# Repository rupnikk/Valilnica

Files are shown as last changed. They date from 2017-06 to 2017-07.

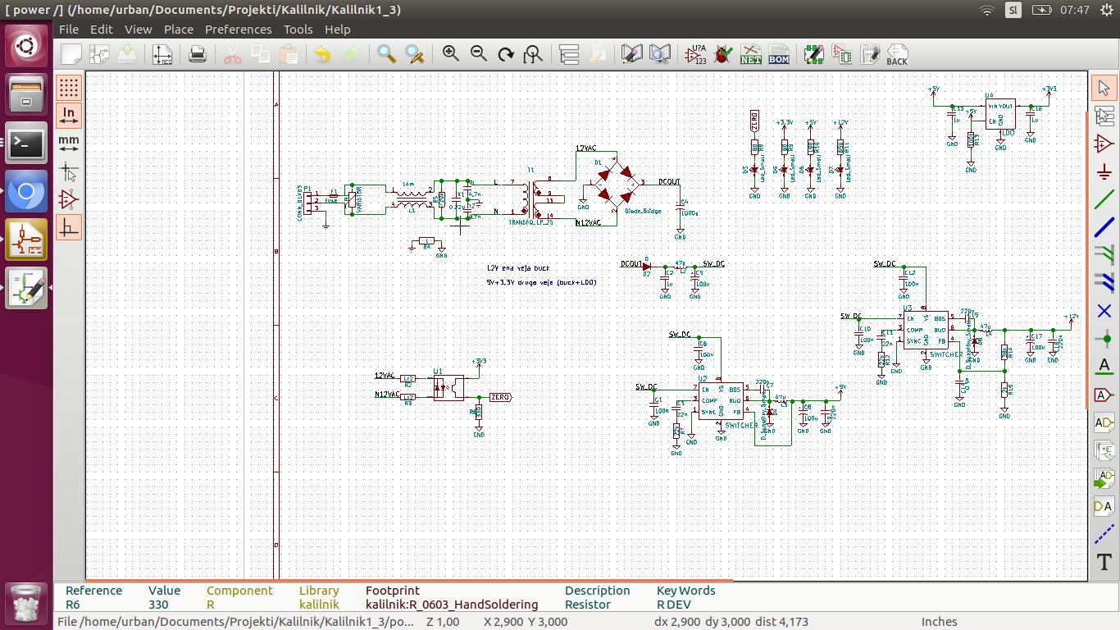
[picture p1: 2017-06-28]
napajanje.jpg

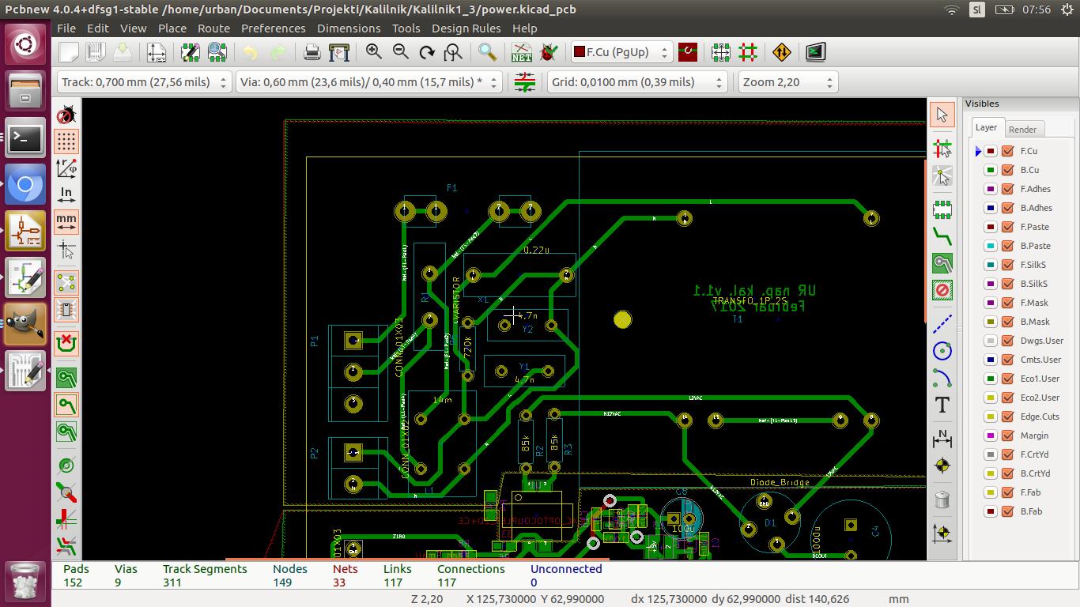
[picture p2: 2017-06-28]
napajanje_pcb.jpg

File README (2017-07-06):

KALILNIK

Urban Rupnik
Zadlog 42, 5274 Črni Vrh
Start: 6. 6. 2016

Navodila za git:
git add . -Af
git commit -am "bla"

Verzija 1.1: 6. 6. 2016
Komentarji k shemi:
	LCD: 	- potenciometer za nastavljanje svetlosti, 
			- R/W = GND => se samo piše v spomin LCD-ja

	Izhodi:	- Luci:		-180 omski upor za nastavitev napetosti, ki 					mora biti na triacu in zagotovitev odprtja 						triaca.
						- 2.4 ohm + 0.2uF -> Snubber za optospojnik
						- 39 ohm + 0.05uF -> Snubber za induktivno breme
			- Grelec:	- brez Snubberjev zato ker je omsko breme

	Tipke: 	- paralelni upor -> pull-up upor (cca. 10k)
			- serijski upor -> ko je pin nastavljen kot vhod in je tipka pritisnjena (nizko stanje na vhodu) skozi tranzistor steče tok, ki je zaradi velike Ugs prevelik in lahko uniči pin. (cca. 220 ohm)

	Enkoder: - 10k pull-up upor, in 10k + 0.1uF C za filter

	MCU: 	- Potrebujemo najmanj 21 digitalnih I/O pinov => najmanjši tak je 32 pinski.
			- ne potrebujemo veliko spomina, niti procesorske moči, tako da bi se odločil za ATtiny88 NIMA možnosti za zunanji kristalni oscilator!!!!!!!!
		- Izbral sem ATMEGA32M1-AU

	Switcher: -http://si.farnell.com/infineon/ifx91041ej-v50/dc-dc-conv-buck-370khz-soic-8/dp/2432504

			- blokirni kondenzatorji cca. 2.2u in 100n

			- pi filter: (1/10*f0) f0=1/(2*pi*sqrt(L*C))

	konektorji: signalni: -jst xhp
			močnostni: 5.08 mm bom potem zbral

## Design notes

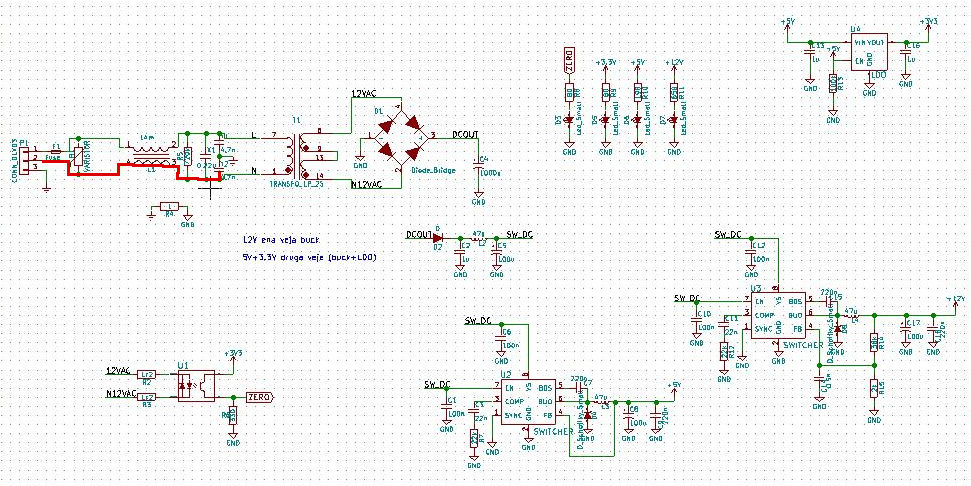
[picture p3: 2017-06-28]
napajanje.png

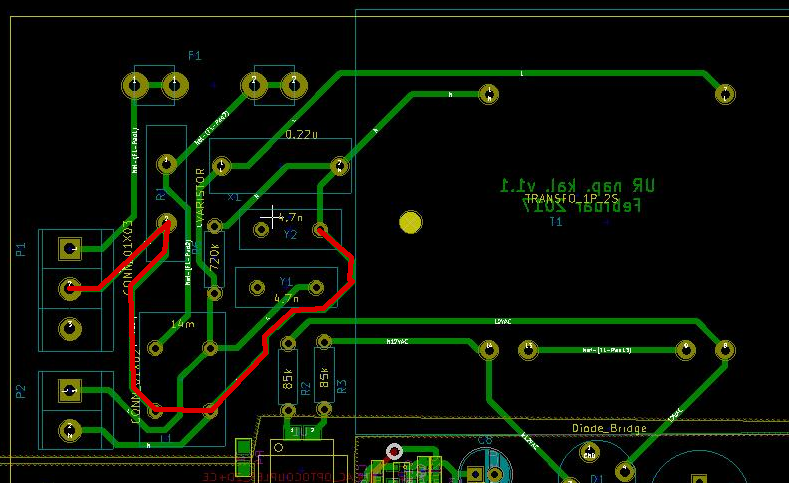
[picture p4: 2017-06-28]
napajanje_pcb.png

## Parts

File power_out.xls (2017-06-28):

Reference | Value | Footprint | Datasheet | Farnell number | Farnell numbere
P4 | CONN_02X03 | kalilnik:IDC_Header_Straight_6pins
U1 | TRIAC_OPTOCOUPLER | kalilnik:DIP-6_W7.62mm_LongPads | http://www.farnell.com/datasheets/2050807.pdf | 1045437
D3 | Led_Small | kalilnik:LED_0_1inch
R4 | 220 | kalilnik:R_0603_HandSoldering
R6 | 180 | kalilnik:CFR100
R8 | 2k4 | kalilnik:CFR100
C3 | 200n | kalilnik:C_5x11_2 | http://www.farnell.com/datasheets/1558295.pdf?_ga=1.154452152.1660152525.1481320514 |  | 1902939
U3 | TRIAC | kalilnik:SOT428_2+1P | http://www.farnell.com/datasheets/1837712.pdf?_ga=1.37489763.278307822.1459272424 | 1757883
R10 | 39 2W | kalilnik:CFR200
C5 | 50n 500V+ | kalilnik:c_60pF |  | 2546307
P5 | CONN_01X02 | kalilnik:CONN_2x1x5.08
D4 | Led_Small | kalilnik:LED_0_1inch
R5 | 220 | kalilnik:R_0603_HandSoldering
R1 | R | kalilnik:R_0603_HandSoldering
D2 | Led_Small | kalilnik:R_0603_HandSoldering
R2 | 220 | kalilnik:R_0603_HandSoldering
R3 | 10k | kalilnik:R_0603_HandSoldering
SW1 | SW_PUSH | kalilnik:TACTILE_SWTICH_4PIN | http://www.farnell.com/datasheets/1914518.pdf?_ga=1.146154420.1660152525.1481320514 | 2320087
C1 | 1u | kalilnik:C_0603_HandSoldering
C2 | 100n | kalilnik:C_0603_HandSoldering
D1 | ESD_1CH | kalilnik:SOD323F | http://www.farnell.com/datasheets/682594.pdf?_ga=1.121054984.1660152525.1481320514 | 8737517
IC1 | ATTINY85-S | kalilnik:SOIC-8_3.9x4.9mm_Pitch1.27mm | http://www.farnell.com/datasheets/1744708.pdf?_ga=1.222685467.1660152525.1481320514 | 1972176
P1 | CONN_01X02 | kalilnik:CONN_2x1x2.54
P2 | CONN_01X02 | kalilnik:CONN_2x1x5.08
U2 | TRIAC_OPTOCOUPLER | kalilnik:DIP-6_W7.62mm_LongPads | http://www.farnell.com/datasheets/2050807.pdf | 1045437
R7 | 180 | kalilnik:CFR100
R9 | 2k4 | kalilnik:CFR100
C4 | 200n | kalilnik:C_5x11_2 | http://www.farnell.com/datasheets/1558295.pdf?_ga=1.154452152.1660152525.1481320514 |  | 1902939
U4 | TRIAC | kalilnik:SOT428_2+1P | http://www.farnell.com/datasheets/1837712.pdf?_ga=1.37489763.278307822.1459272424 | 1757883
R11 | 39 2W | kalilnik:CFR200
C6 | 50n 500V+ | kalilnik:c_60pF |  | 2546307
P6 | CONN_01X02 | kalilnik:CONN_2x1x5.08
P3 | CONN_01X03 | kalilnik:CONN_3x1x2.54

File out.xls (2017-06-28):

Reference | Value | Footprint | Datasheet | Farnell number
P3 | CONN_02X03 | kalilnik:IDC_Header_Straight_6pins
R1 | 80 | kalilnik:R_0603_HandSoldering
D2 | Led_Small | kalilnik:R_0603_HandSoldering
R4 | 220 | kalilnik:R_0603_HandSoldering
R5 | 10k | kalilnik:R_0603_HandSoldering
SW1 | SW_PUSH | kalilnik:TACTILE_SWTICH_4PIN
C1 | 1u | kalilnik:C_0603_HandSoldering
C2 | 100n | kalilnik:C_0603_HandSoldering
D1 | ESD_1CH | kalilnik:SOD323F | http://www.farnell.com/datasheets/682594.pdf?_ga=1.121054984.1660152525.1481320514 | 8737517
P2 | CONN_01X02 | kalilnik:CONN_2x1x2.54
IC1 | ATTINY24A-SS | kalilnik:SOIC-14_3.9x8.7mm_Pitch1.27mm
P1 | CONN_01X04 | kalilnik:CONN_4x1x2.54
R10 | 220 | kalilnik:R_0603_HandSoldering
P9 | CONN_01X05 | kalilnik:CONN_5x1x2.54
Q1 | Q_NMOS_GDS | kalilnik:SOT89-3_Housing_Handsoldering_123 | http://www.farnell.com/datasheets/612773.pdf?_ga=1.108842754.1660152525.1481320514 | 1834055
R12 | 220 | kalilnik:R_0603_HandSoldering
Q3 | Q_NMOS_GDS | kalilnik:SOT89-3_Housing_Handsoldering_123 | http://www.farnell.com/datasheets/612773.pdf?_ga=1.108842754.1660152525.1481320514 | 1834055
R13 | 220 | kalilnik:R_0603_HandSoldering
Q4 | Q_NMOS_GDS | kalilnik:SOT89-3_Housing_Handsoldering_123 | http://www.farnell.com/datasheets/612773.pdf?_ga=1.108842754.1660152525.1481320514 | 1834055
Q5 | Q_NMOS_GDS | kalilnik:SOT89-3_Housing_Handsoldering_123 | http://www.farnell.com/datasheets/612773.pdf?_ga=1.108842754.1660152525.1481320514 | 1834055
R14 | 220 | kalilnik:R_0603_HandSoldering
R2 | 190 | kalilnik:R_0603_HandSoldering
D3 | Led_Small | kalilnik:R_0603_HandSoldering
R3 | 650 | kalilnik:R_0603_HandSoldering
D4 | Led_Small | kalilnik:R_0603_HandSoldering
Q2 | Q_NMOS_GDS | kalilnik:SOT89-3_Housing_Handsoldering_123 | http://www.farnell.com/datasheets/612773.pdf?_ga=1.108842754.1660152525.1481320514 | 1834055
R11 | 220 | kalilnik:R_0603_HandSoldering
P8 | CONN_01X02 | kalilnik:CONN_2x1x5.08
P5 | CONN_01X03 | kalilnik:CONN_3x1x2.54
P4 | CONN_01X03 | kalilnik:CONN_3x1x2.54
P7 | CONN_01X03 | kalilnik:CONN_3x1x2.54
P6 | CONN_01X03 | kalilnik:CONN_3x1x2.54
R8 | 4.7k | kalilnik:R_0603_HandSoldering
R6 | 4.7k | kalilnik:R_0603_HandSoldering
R7 | 4.7k | kalilnik:R_0603_HandSoldering
R9 | 4.7k | kalilnik:R_0603_HandSoldering

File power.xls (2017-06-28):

Reference | Value | Footprint | Datasheet | Farnell number
U4 | LDO | kalilnik:SOT23-5 | http://www.farnell.com/datasheets/1720528.pdf?_ga=1.150340662.1660152525.1481320514 | 2363036
C13 | 1u | kalilnik:C_0603_HandSoldering
R13 | 100k | kalilnik:R_0603_HandSoldering
C16 | 1u | kalilnik:C_0603_HandSoldering
F1 | Fuse | kalilnik:Fuseholder_Fuse_5x20 | http://www.farnell.com/datasheets/2036023.pdf?_ga=1.179105700.1660152525.1481320514 | 1271632
R1 | VARISTOR | kalilnik:VARISTOR_MOV-14D431KTR | http://www.farnell.com/datasheets/2026684.pdf?_ga=1.122545291.1660152525.1481320514 | 2250941
C4 | 1000u | kalilnik:C_13_21_5 | http://www.farnell.com/datasheets/1723232.pdf?_ga=1.246941828.1660152525.1481320514 | 9451323
D1 | Diode_Bridge | kalilnik:CIRC_BRIDGE_RECT
C2 | 1u | kalilnik:R_0603_HandSoldering
L2 | 47u | kalilnik:TYS4018470M-10 | http://www.farnell.com/datasheets/1685911.pdf?_ga=1.73640273.278307822.1459272424 | 2292522
C6 | 100n | kalilnik:C_0603_HandSoldering
U2 | SWITCHER | kalilnik:SOIC-8-N | http://www.farnell.com/datasheets/1836350.pdf?_ga=1.108659649.278307822.1459272424 | 2432504
C5 | 100u | kalilnik:C_Radial_D6.3_L11.2_P2.5 | http://www.farnell.com/datasheets/1723232.pdf?_ga=1.150990774.1660152525.1481320514 | 9451080
C1 | 100n | kalilnik:C_0603_HandSoldering
D2 | D | kalilnik:SOD323F | http://www.farnell.com/datasheets/109671.pdf?_ga=1.108711873.278307822.1459272424 | 1757770
C3 | 22n | kalilnik:C_0603_HandSoldering
R7 | 22k | kalilnik:R_0603_HandSoldering
D4 | D_Schottky_Small | kalilnik:SOD323F | http://www.farnell.com/datasheets/701039.pdf?_ga=1.62103663.278307822.1459272424 | 2575120
C7 | 220n | kalilnik:C_0603_HandSoldering
C9 | 220n | kalilnik:C_0603_HandSoldering
U3 | SWITCHER | kalilnik:SOIC-8-N | http://www.farnell.com/datasheets/1836350.pdf?_ga=1.210043029.1660152525.1481320514 | 2480506
U1 | TRIAC_OPTOCOUPLER_2D+CE | kalilnik:SFH620-SMD_4pin | http://www.farnell.com/datasheets/2049908.pdf?_ga=1.247262340.1660152525.1481320514 | 1469585
R2 | 85k | kalilnik:CFR25 |  | 2329708
R6 | 33k | kalilnik:R_0603_HandSoldering
L1 | 14m | kalilnik:FILTER_SU9V | http://www.farnell.com/datasheets/1760497.pdf?_ga=1.122603659.1660152525.1481320514 | 2364377
P1 | CONN_01X03 | kalilnik:CONN_3x1x5.08 | http://www.farnell.com/datasheets/1493498.pdf?_ga=1.188002216.1660152525.1481320514 | 2008020
X1 | 0.22u | kalilnik:X2_B32922 | http://si.farnell.com/epcos/b32922c3224m000/cap-film-pp-220nf-305vac-rad/dp/1112842 | 1112842
Y2 | 4.7n | kalilnik:Y2_L20C7H | http://www.farnell.com/datasheets/2058629.pdf?_ga=1.116402950.1660152525.1481320514 | 2576709
R4 | 1 | kalilnik:R_0805_HandSoldering
P4 | CONN_01X04 | kalilnik:CONN_4x1x2.54
P2 | CONN_01X02 | kalilnik:CONN_2x1x5.08
R5 | 720k | kalilnik:CFR25 | http://www.farnell.com/datasheets/1723854.pdf?_ga=1.184545190.1660152525.1481320514 | 2329704
Y1 | 4.7n | kalilnik:Y2_L20C7H | http://www.farnell.com/datasheets/2058629.pdf?_ga=1.116402950.1660152525.1481320514 | 2576709
T1 | TRANSFO_1P_2S | kalilnik:TRAFO_17_89_1314 | http://www.farnell.com/datasheets/41284.pdf?_ga=1.183495462.1660152525.1481320514 | 1214618
R3 | 85k | kalilnik:CFR25 |  | 2329708
L3 | 47u | kalilnik:TYS4018470M-10 | http://www.farnell.com/datasheets/1685911.pdf?_ga=1.73640273.278307822.1459272424 | 2292522
R15 | 2k | kalilnik:R_0603_HandSoldering
R14 | 38k | kalilnik:R_0603_HandSoldering
C14 | 0.5n | kalilnik:C_0603_HandSoldering
C18 | 220n | kalilnik:C_0603_HandSoldering
C12 | 100n | kalilnik:C_0603_HandSoldering
C10 | 100n | kalilnik:C_0603_HandSoldering
C11 | 22n | kalilnik:C_0603_HandSoldering
R12 | 22k | kalilnik:R_0603_HandSoldering
D8 | D_Schottky_Small | kalilnik:SOD323F | http://www.farnell.com/datasheets/701039.pdf?_ga=1.62103663.278307822.1459272424 | 2575120
C15 | 220n | kalilnik:C_0603_HandSoldering
L4 | 47u | kalilnik:TYS4018470M-10 | http://www.farnell.com/datasheets/1685911.pdf?_ga=1.73640273.278307822.1459272424 | 2292522
R10 | 190 | kalilnik:R_0603_HandSoldering
D6 | Led_Small | kalilnik:R_0603_HandSoldering |  | 2426215
R11 | 650 | kalilnik:R_0603_HandSoldering
D7 | Led_Small | kalilnik:R_0603_HandSoldering |  | 2426215
R8 | 80 | kalilnik:R_0603_HandSoldering
D3 | Led_Small | kalilnik:R_0603_HandSoldering |  | 2463988
R9 | 80 | kalilnik:R_0603_HandSoldering
D5 | Led_Small | kalilnik:R_0603_HandSoldering |  | 2426215
P3 | CONN_01X03 | kalilnik:CONN_3x1x2.54
P5 | CONN_01X03 | kalilnik:CONN_3x1x2.54
C8 | 100u | kalilnik:C_Radial_D6.3_L11.2_P2.5 | http://www.farnell.com/datasheets/1723232.pdf?_ga=1.150990774.1660152525.1481320514 | 9451080
C17 | 100u | kalilnik:C_Radial_D6.3_L11.2_P2.5 | http://www.farnell.com/datasheets/1723232.pdf?_ga=1.150990774.1660152525.1481320514 | 9451080

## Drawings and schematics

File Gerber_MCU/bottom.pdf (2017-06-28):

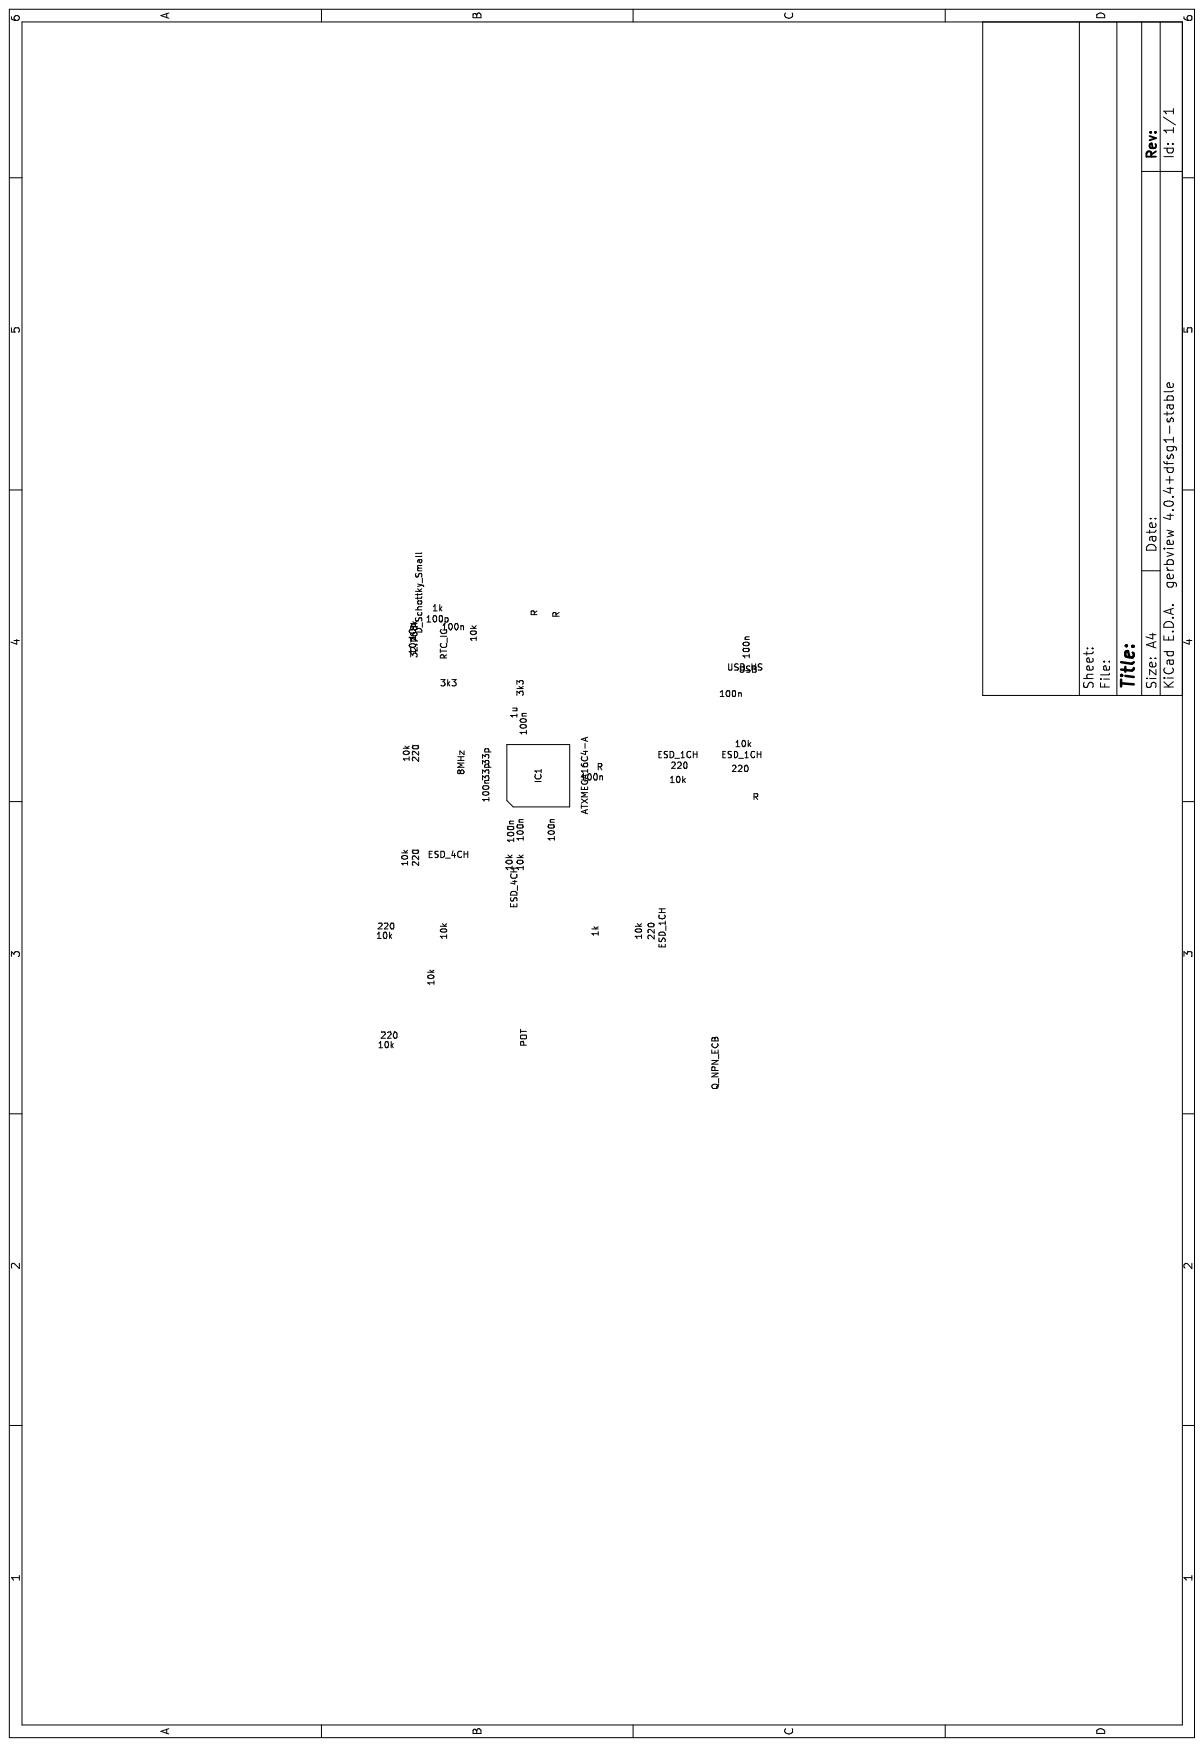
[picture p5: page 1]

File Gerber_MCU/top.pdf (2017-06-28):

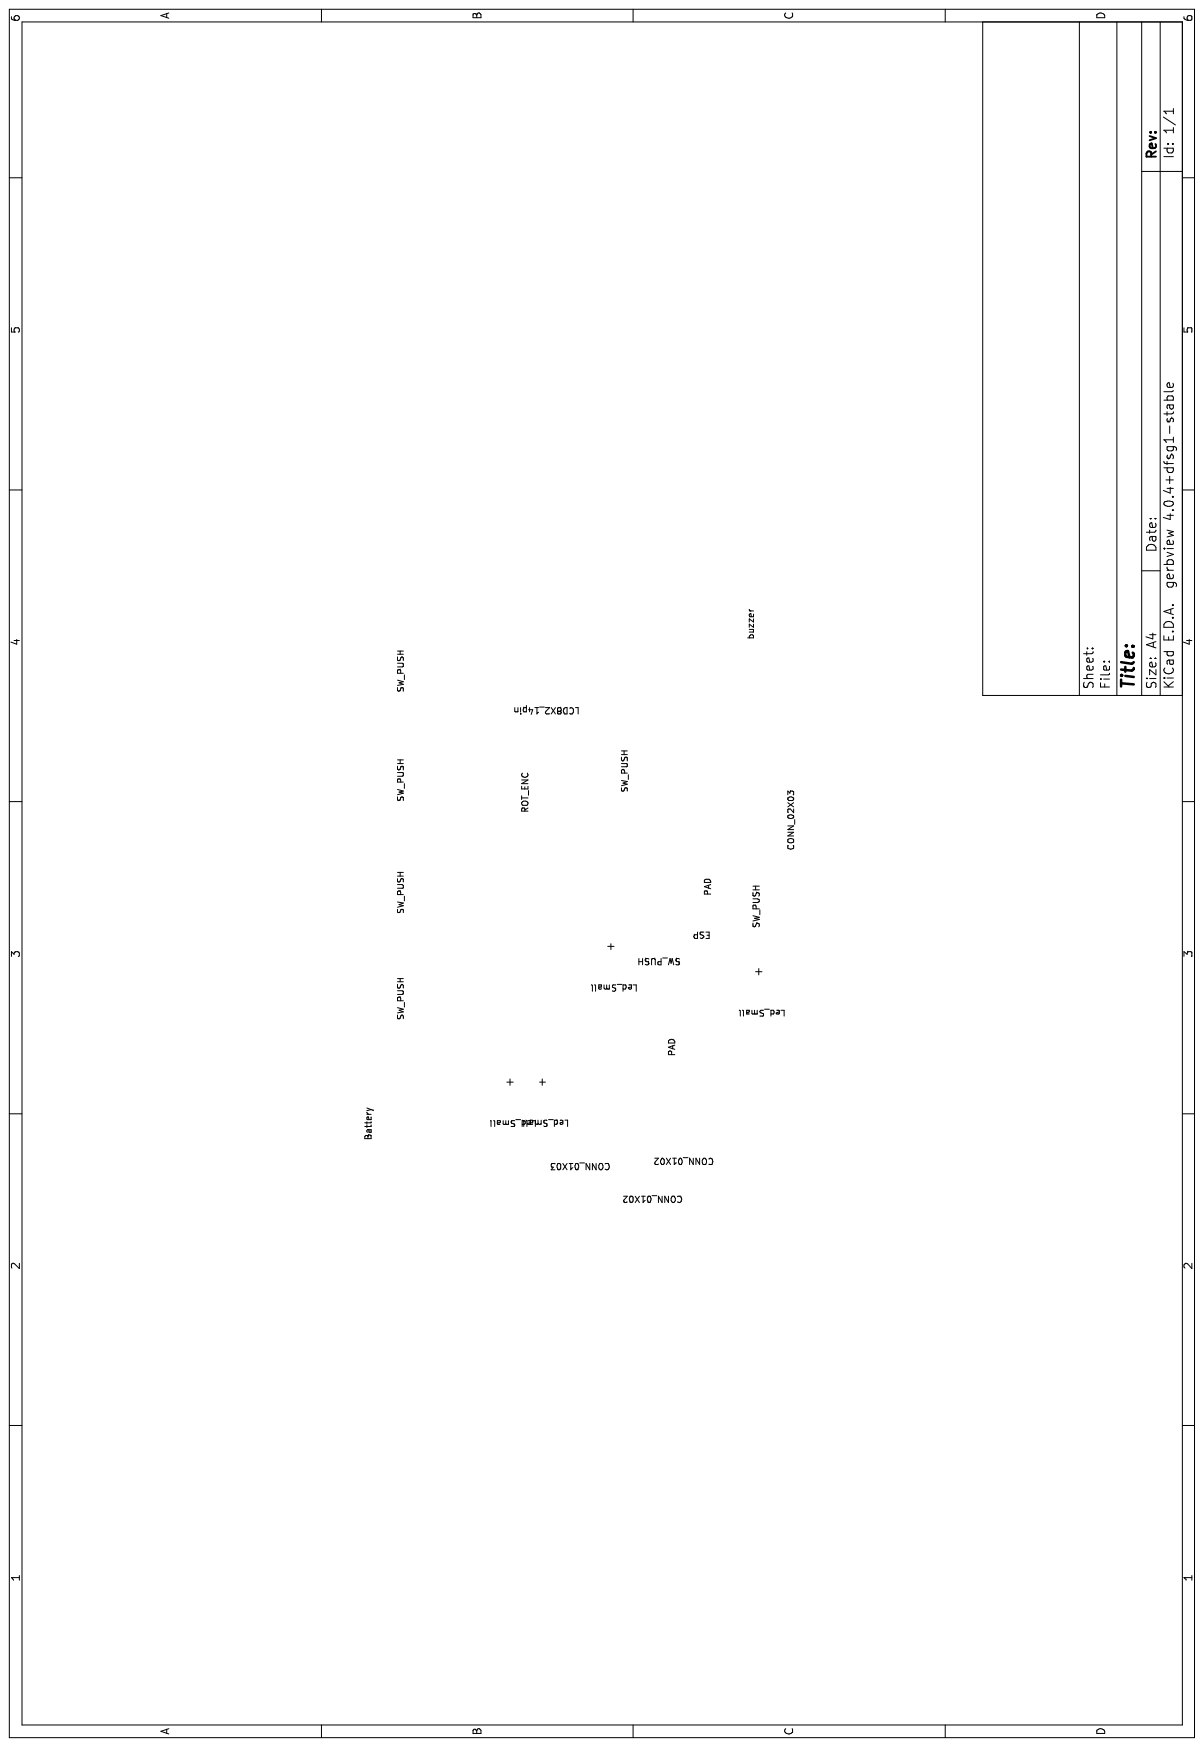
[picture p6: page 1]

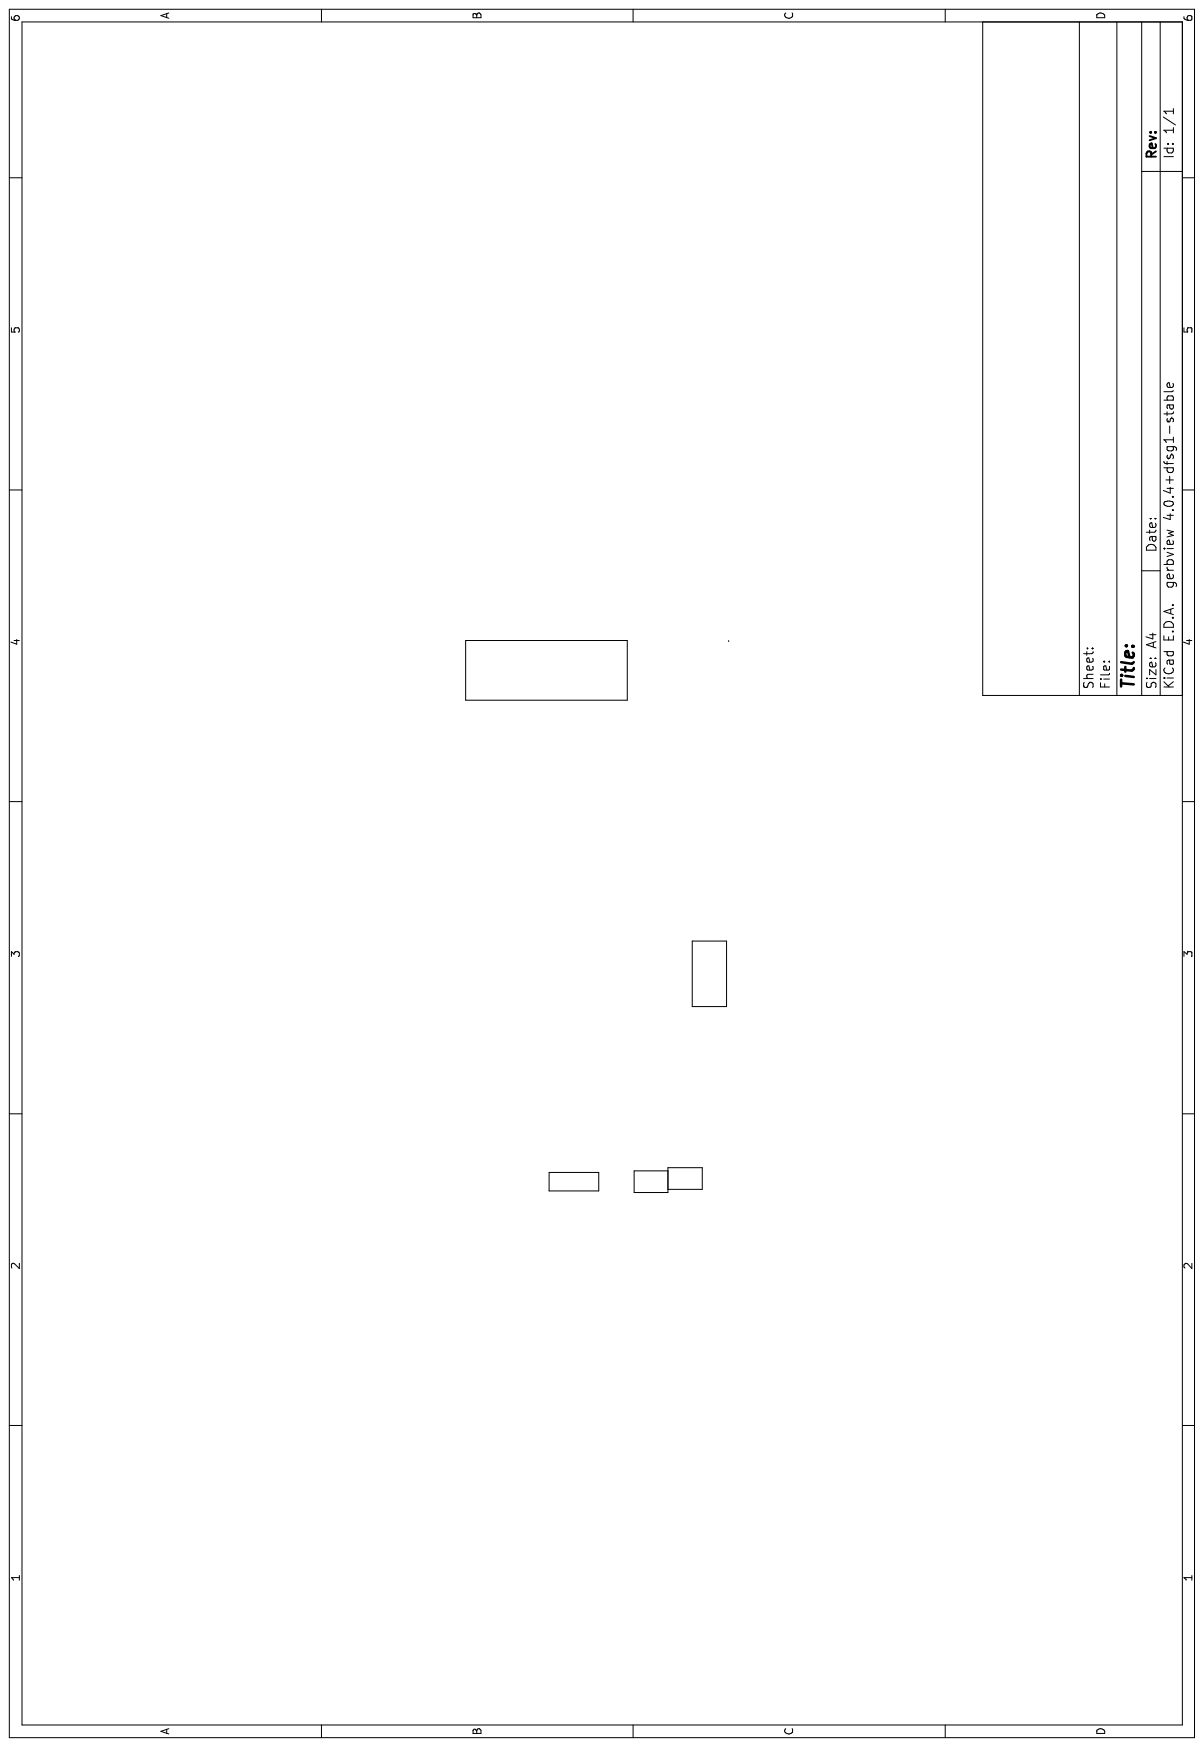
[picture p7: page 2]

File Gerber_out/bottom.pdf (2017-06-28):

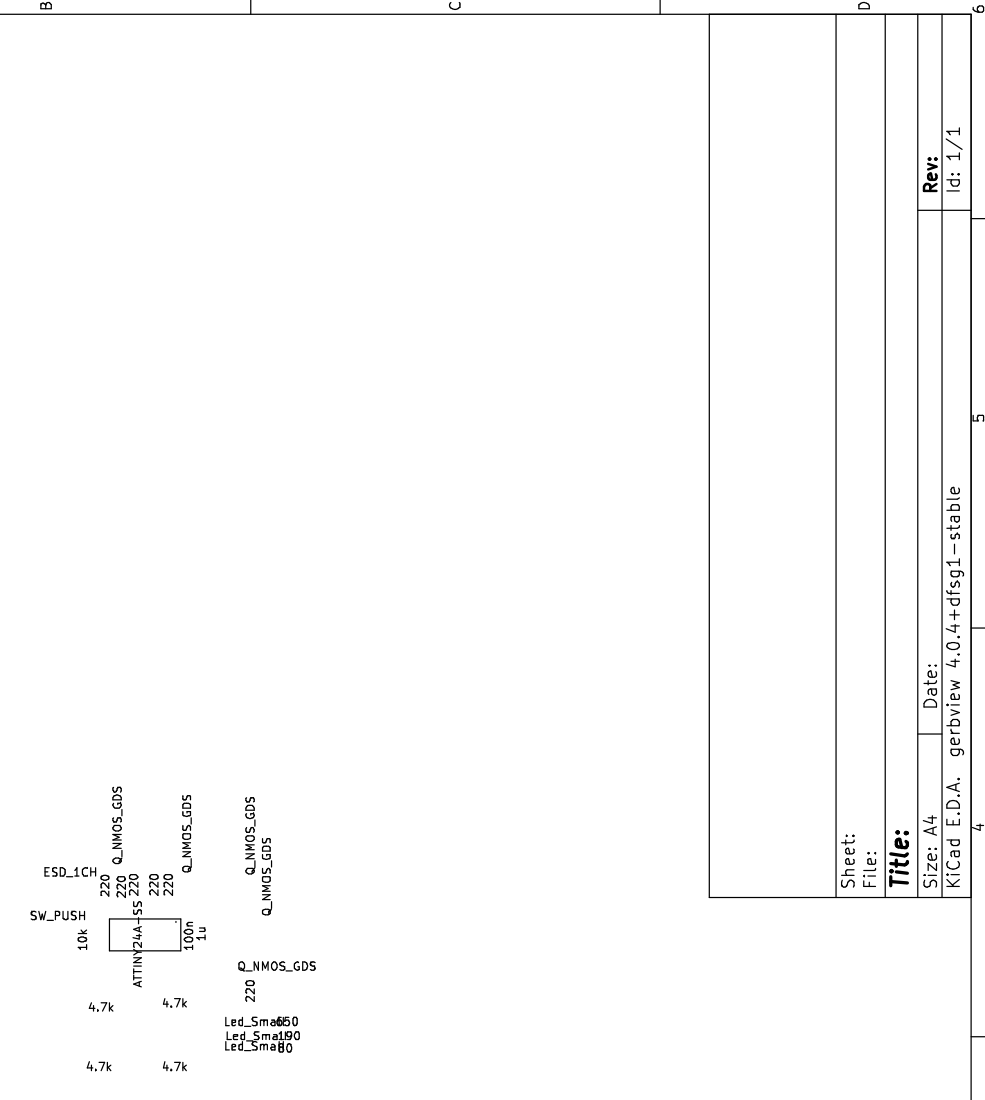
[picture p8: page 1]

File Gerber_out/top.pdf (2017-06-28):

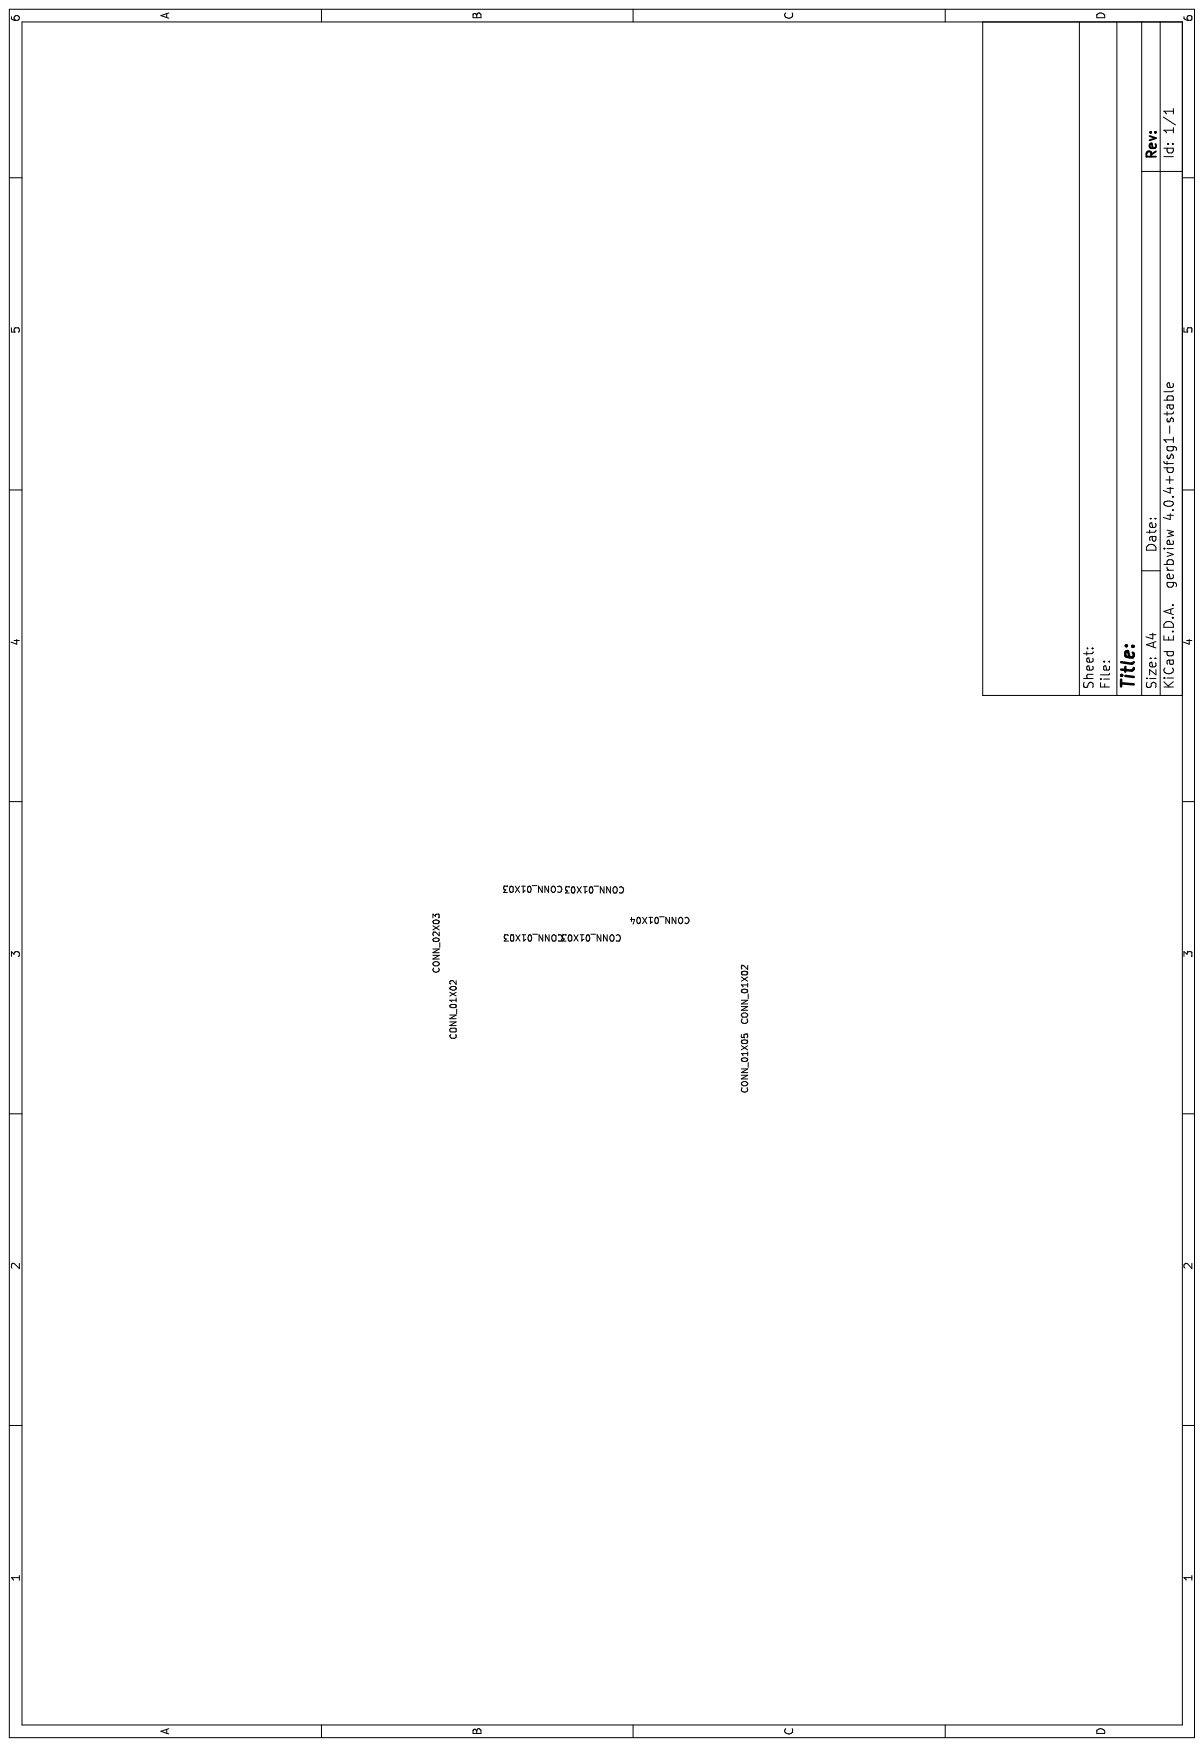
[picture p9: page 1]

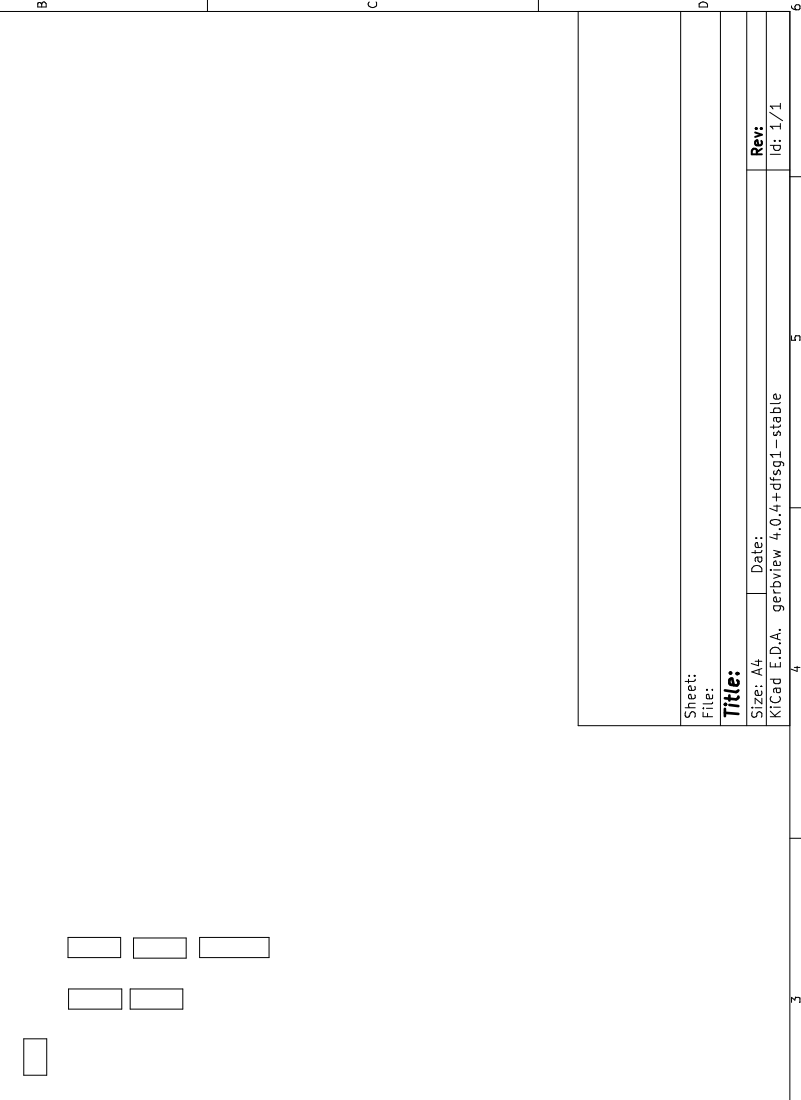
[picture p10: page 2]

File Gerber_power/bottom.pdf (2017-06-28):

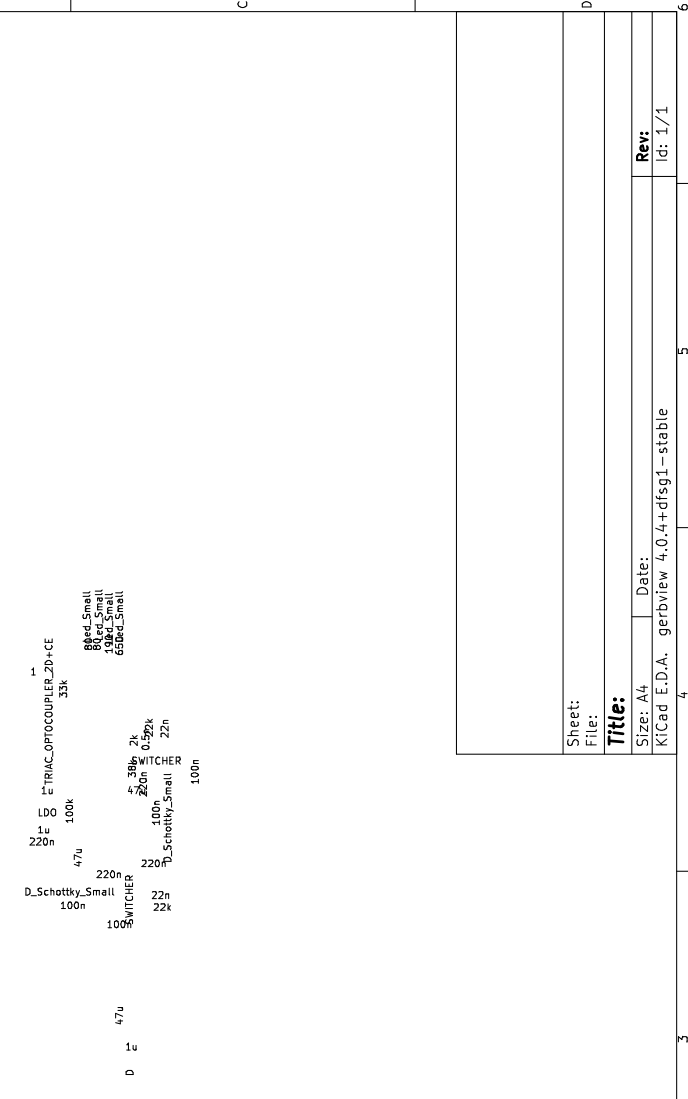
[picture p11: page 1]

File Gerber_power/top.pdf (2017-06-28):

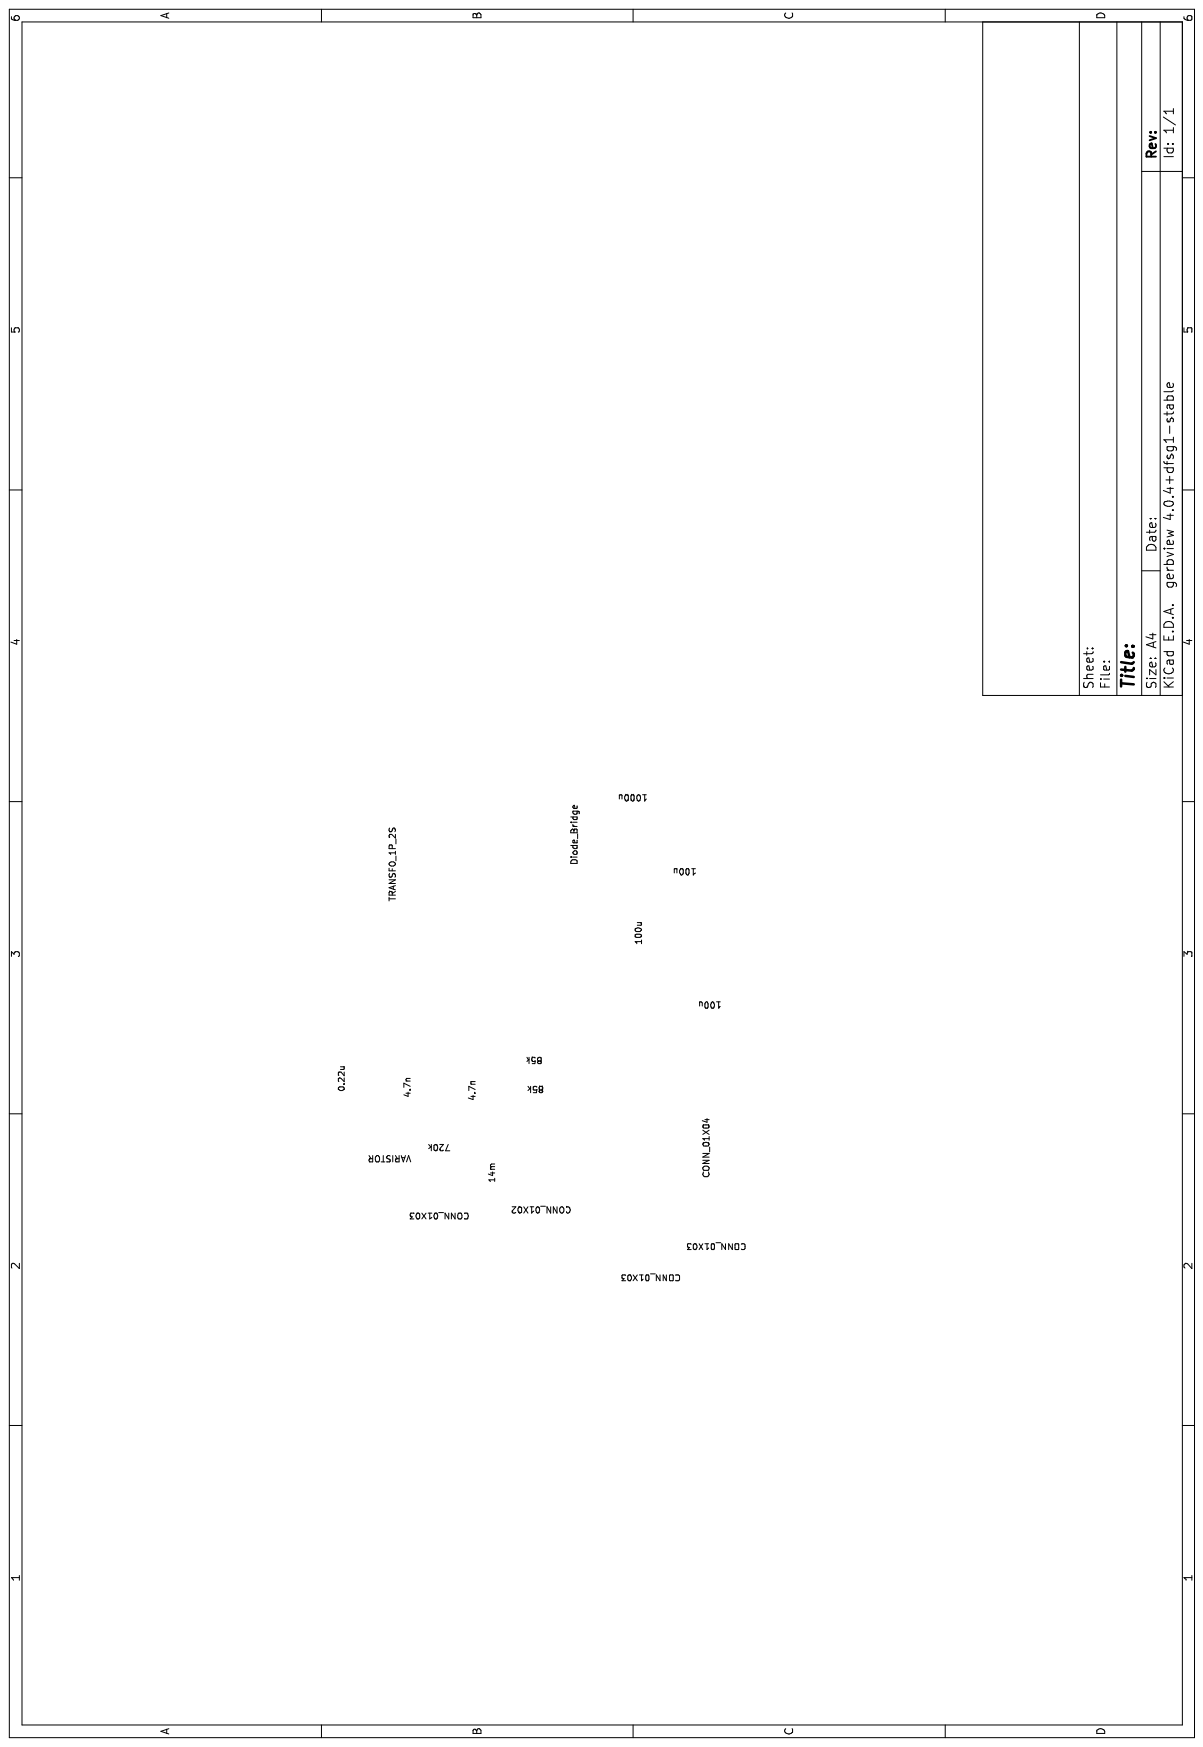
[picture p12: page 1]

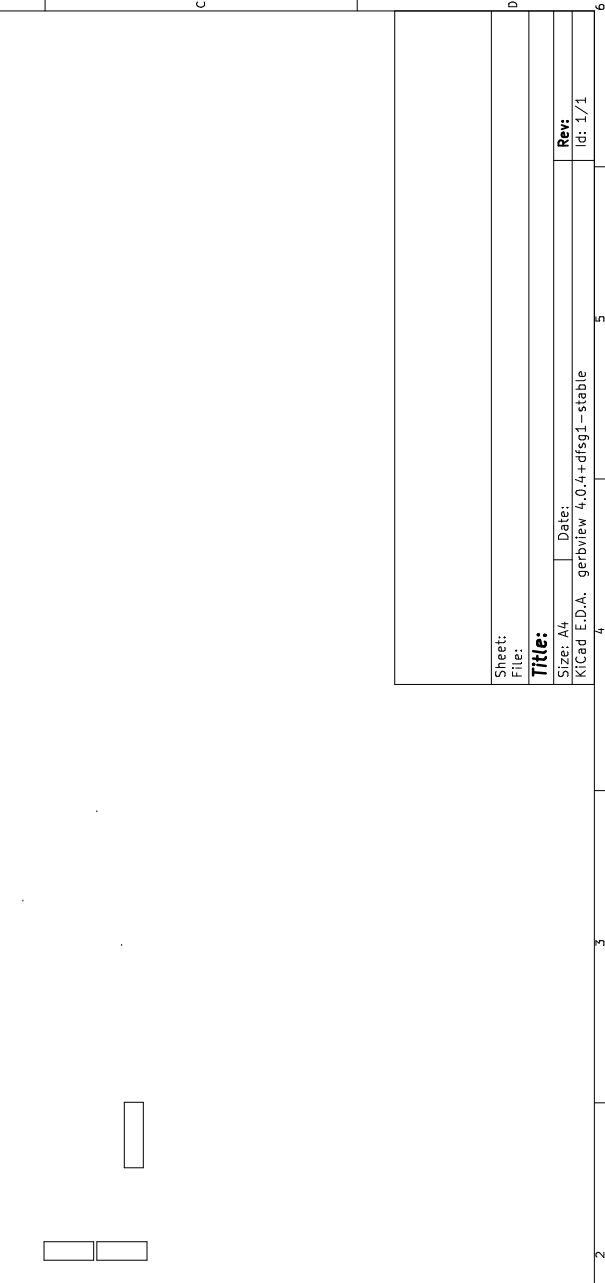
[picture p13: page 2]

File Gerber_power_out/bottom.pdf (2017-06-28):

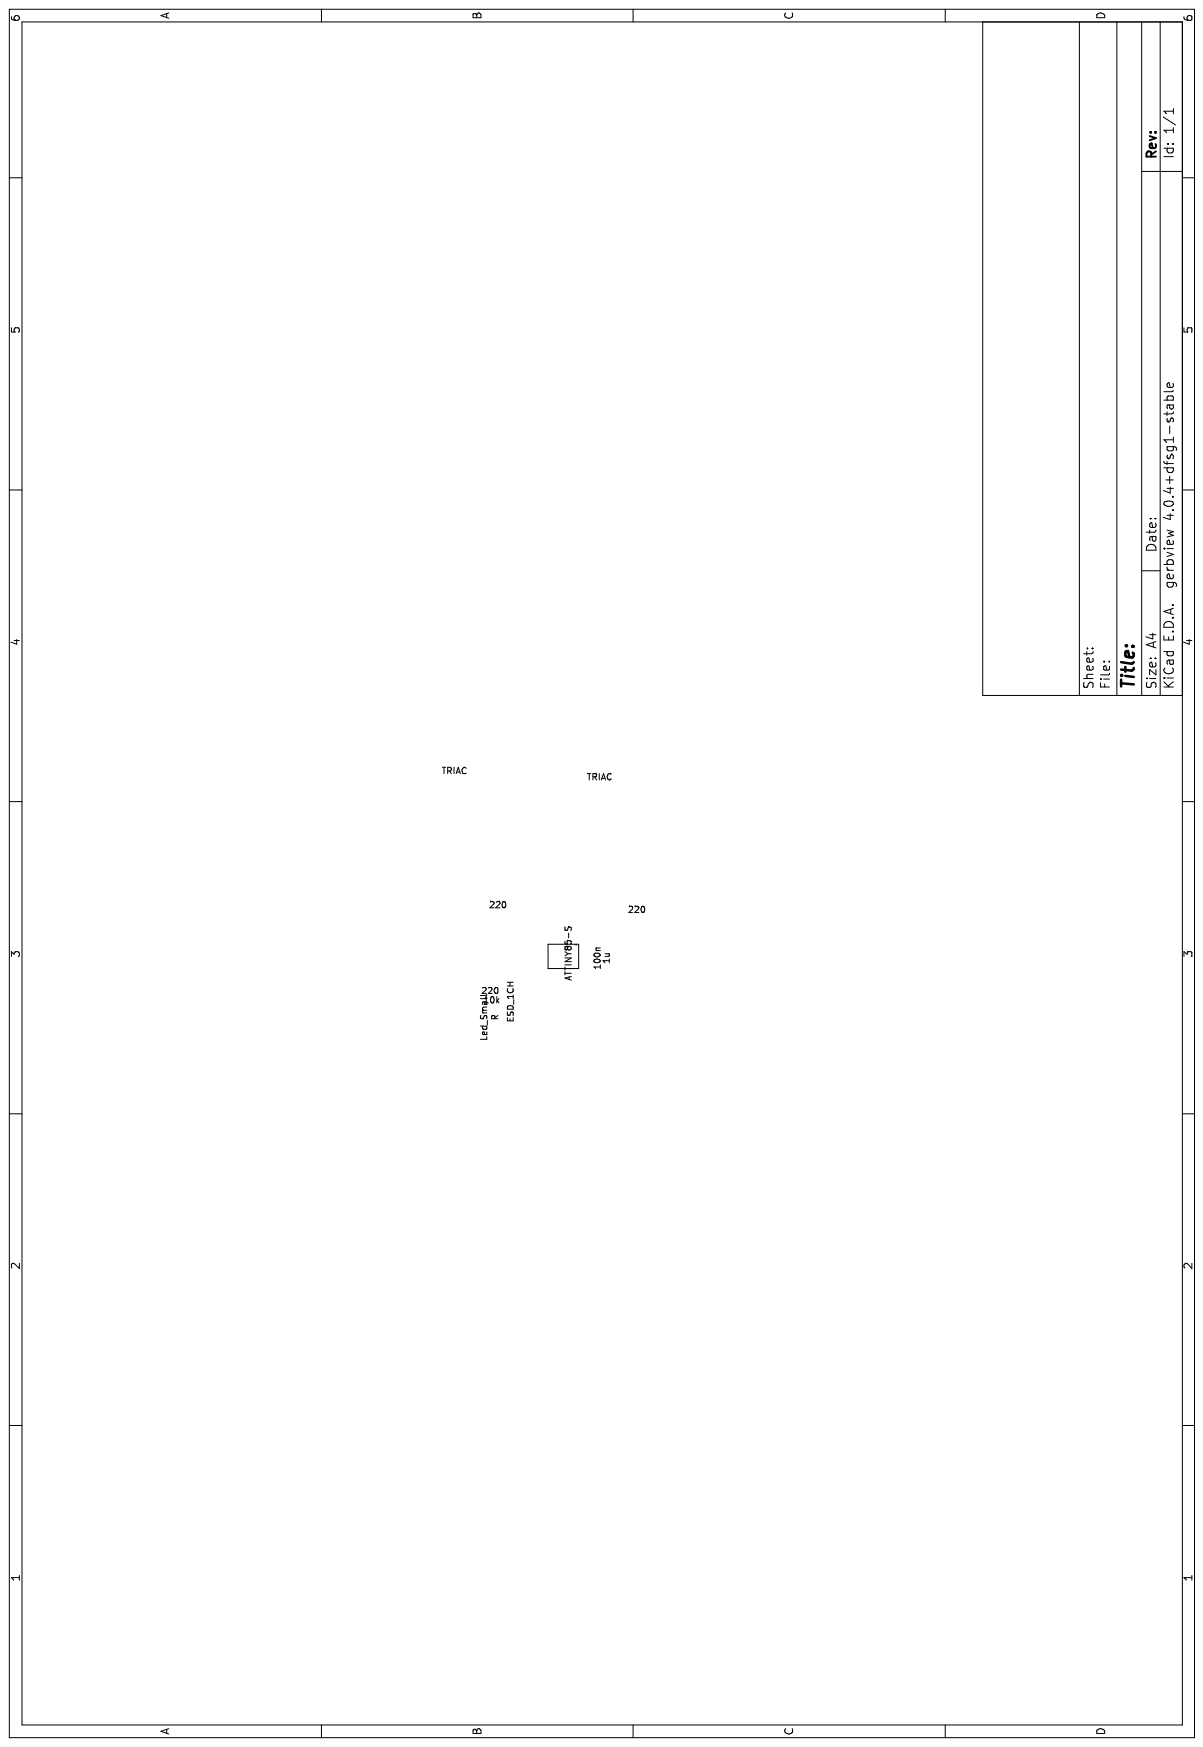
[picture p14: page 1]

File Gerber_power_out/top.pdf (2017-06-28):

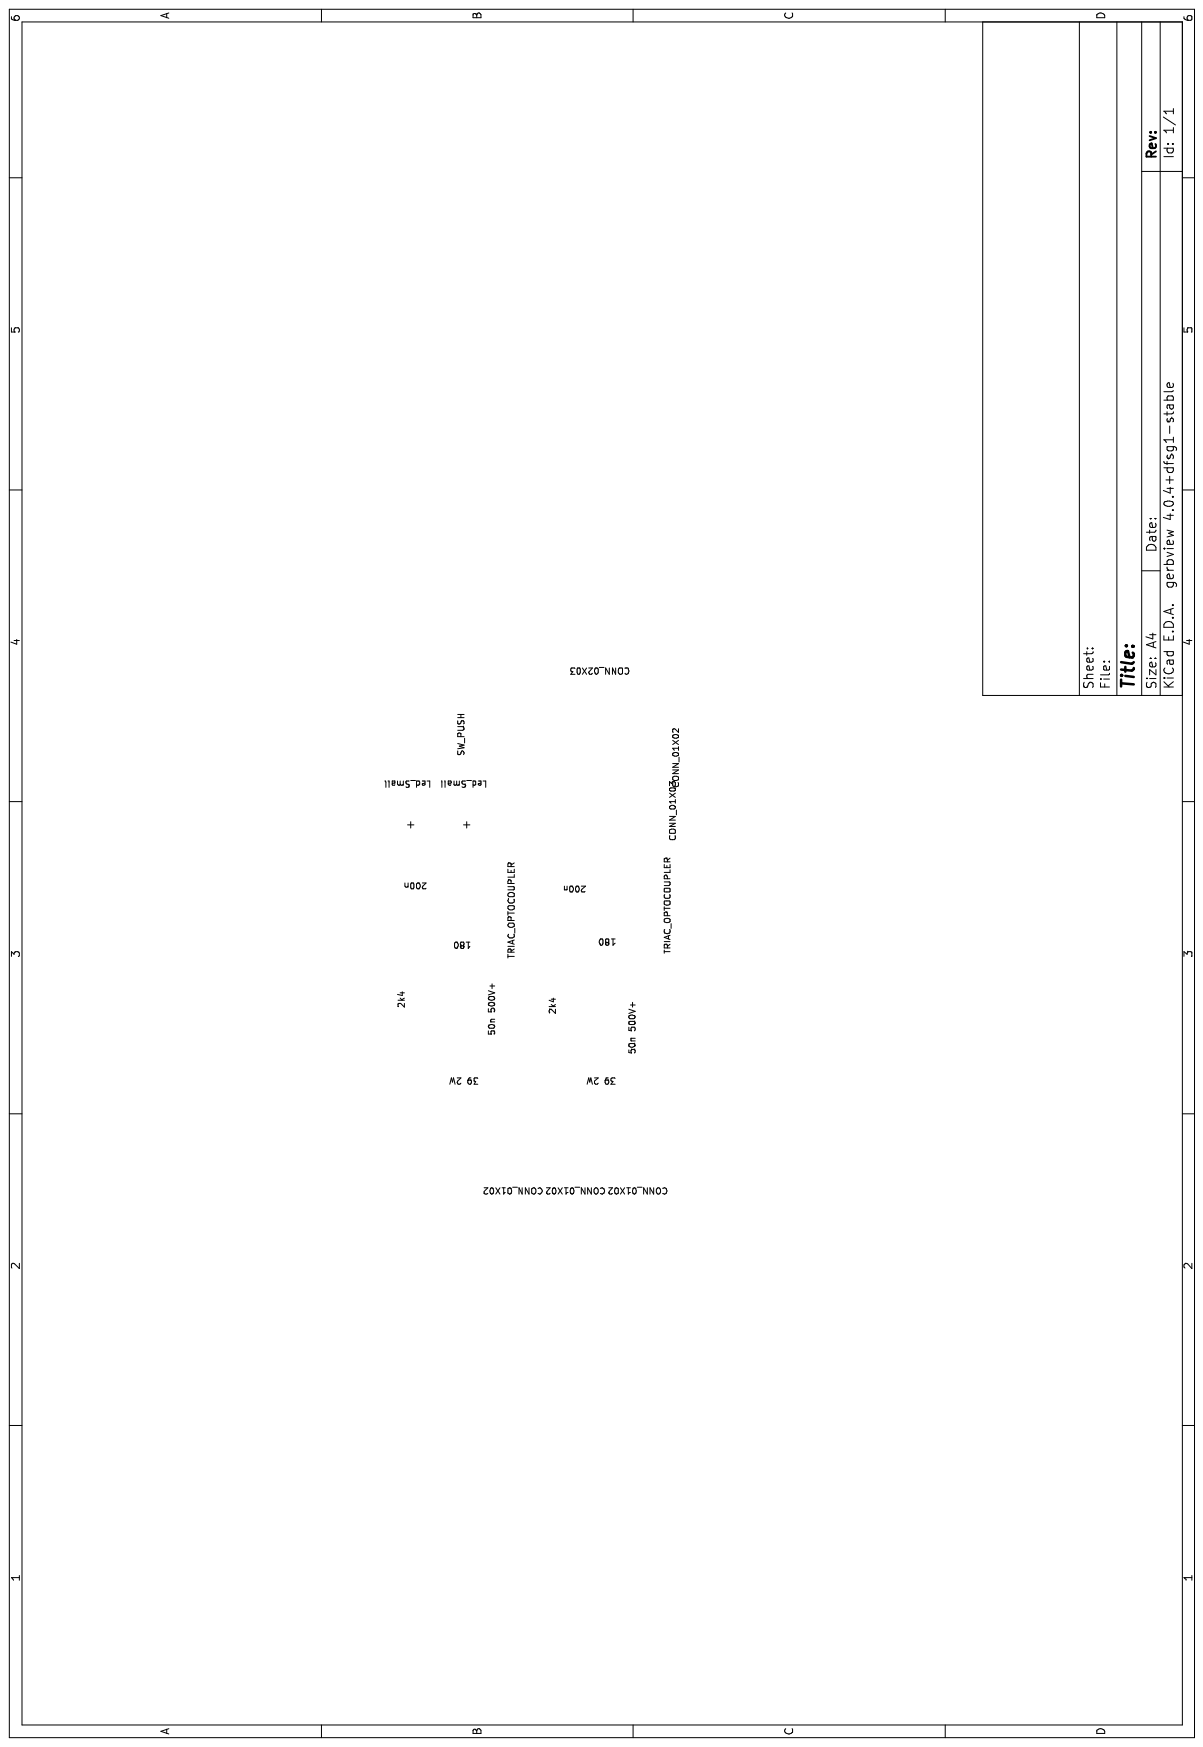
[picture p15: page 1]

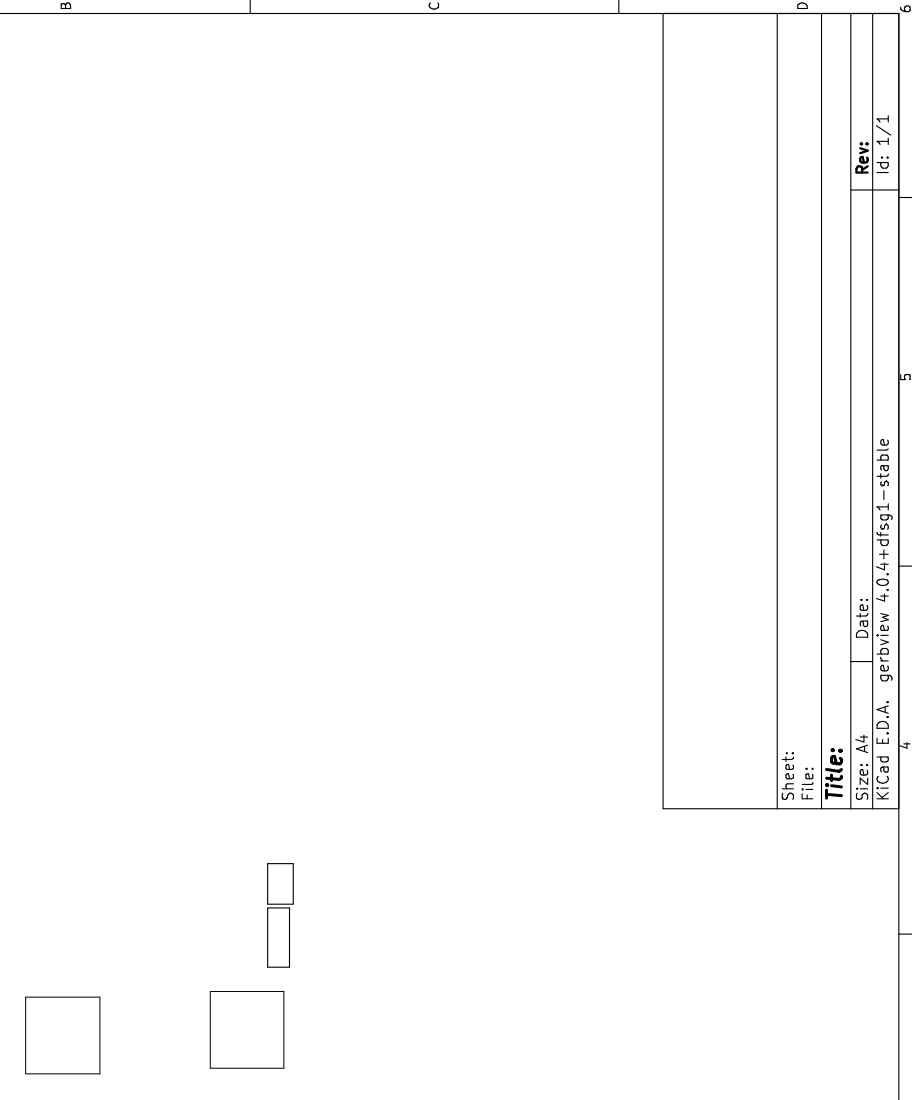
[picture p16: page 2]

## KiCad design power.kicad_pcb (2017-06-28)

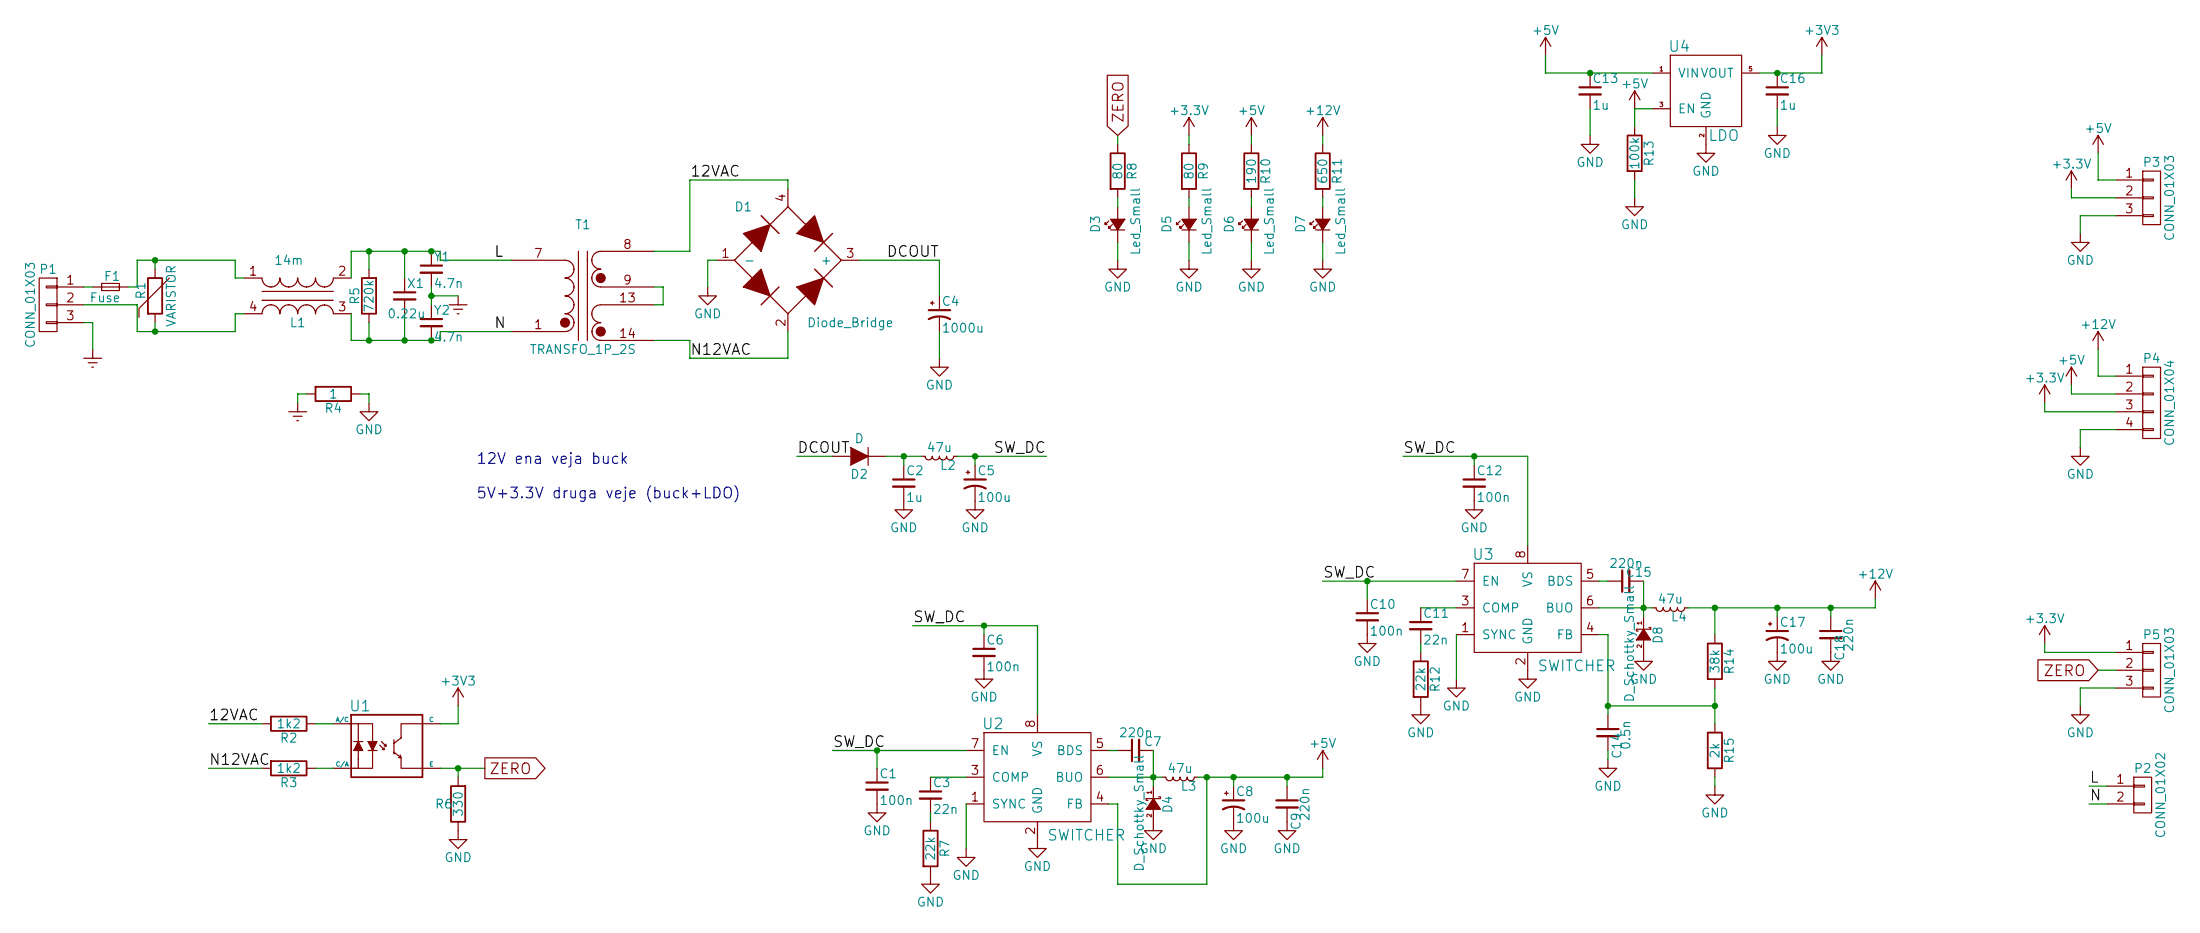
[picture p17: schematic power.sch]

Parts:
C1, C6, C10, C12: 100n; C_0603_HandSoldering
C2: 1u; R_0603_HandSoldering
C3, C11: 22n; C_0603_HandSoldering
C4: 1000u; C_13_21_5; Farnell number 9451323
C5, C8, C17: 100u; C_Radial_D6.3_L11.2_P2.5; Farnell number 9451080
C7, C9, C15, C18: 220n; C_0603_HandSoldering
C13, C16: 1u; C_0603_HandSoldering
C14: 0.5n; C_0603_HandSoldering
D1: Diode_Bridge; CIRC_BRIDGE_RECT
D2: D; SOD323F; Farnell number 1757770
D3: Led_Small; R_0603_HandSoldering; Farnell number 2463988
D4, D8: D_Schottky_Small; SOD323F; Farnell number 2575120
D5, D6, D7: Led_Small; R_0603_HandSoldering; Farnell number 2426215
F1: Fuse; Fuseholder_Fuse_5x20; Farnell number 1271632
L1: 14m; FILTER_SU9V; Farnell number 2364377
L2, L3, L4: 47u; TYS4018470M-10; Farnell number 2292522
P1: CONN_01X03; CONN_3x1x5.08; Farnell number 2008020
P2: CONN_01X02; CONN_2x1x5.08
P3, P5: CONN_01X03; CONN_3x1x2.54
P4: CONN_01X04; CONN_4x1x2.54
R1: VARISTOR; VARISTOR_MOV-14D431KTR; Farnell number 2250941
R2, R3: 1k2; CFR25; Farnell number 2329708
R4: 1; R_0805_HandSoldering
R5: 720k; CFR25; Farnell number 2329704
R6: 330; R_0603_HandSoldering
R7, R12: 22k; R_0603_HandSoldering
R8, R9: 80; R_0603_HandSoldering
R10: 190; R_0603_HandSoldering
R11: 650; R_0603_HandSoldering
R13: 100k; R_0603_HandSoldering
R14: 38k; R_0603_HandSoldering
R15: 2k; R_0603_HandSoldering
T1: TRANSFO_1P_2S; TRAFO_17_89_1314; Farnell number 1214618
U1: TRIAC_OPTOCOUPLER_2D+CE; SFH620-SMD_4pin; Farnell number 1469585
U2: SWITCHER; SOIC-8-N; Farnell number 2432504
U3: SWITCHER; SOIC-8-N; Farnell number 2480506
U4: LDO; SOT23-5; Farnell number 2363036
X1: 0.22u; X2_B32922; Farnell number 1112842
Y1, Y2: 4.7n; Y2_L20C7H; Farnell number 2576709

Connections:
+5V: C8.1, C9.1, C13.1, L3.1, P3.1, P4.2, R10.1, R13.1, U2.4 (FB), U4.1 (VIN), U4.3 (EN)
+12V: C17.1, C18.1, L4.1, P4.1, R11.1, R14.1
/12VAC: D1.4, R2.2, T1.8 (SB)
/DCOUT: C4.1, D1.3 (+), D2.2 (A)
/L: L1.2 (AB), P2.1, R5.2, T1.7 (AA), X1.1, Y1.1
/N: L1.3 (SA), P2.2, R5.1, T1.1 (AB), X1.2, Y2.2
/N12VAC: D1.2, R3.2, T1.14 (SC)
/SW_DC: C1.1, C5.1, C6.1, C10.1, C12.1, L2.1, U2.7 (EN), U2.8 (VS), U3.7 (EN), U3.8 (VS)
Earth: P1.3, R4.2, Y1.2, Y2.1
GND: C1.2, C2.2, C4.2, C5.2, C6.2, C8.2, C9.2, C10.2, C12.2, C13.2, C14.2, C16.2, C17.2, C18.2, D1.1 (-), D3.1 (K), D4.2 (A), D5.1 (K), D6.1 (K), D7.1 (K), D8.2 (A), P3.3, P4.4, P5.3, R4.1, R6.1, R7.2, R12.2, R13.2, R15.2, U2.1 (SYNC), U2.2 (GND), U3.1 (SYNC), U3.2 (GND), U4.2 (GND)
unnamed: C2.1, D2.1 (K), L2.2
unnamed: C3.1, U2.3 (COMP)
unnamed: C3.2, R7.1
unnamed: C7.1, U2.5 (BDS)
unnamed: C7.2, D4.1 (K), L3.2, U2.6 (BUO)
unnamed: C11.1, U3.3 (COMP)
unnamed: C11.2, R12.1
unnamed: C14.1, R14.2, R15.1, U3.4 (FB)
unnamed: C15.1, U3.5 (BDS)
unnamed: C15.2, D8.1 (K), L4.2, U3.6 (BUO)
unnamed: D3.2 (A), R8.2
unnamed: D5.2 (A), R9.2
unnamed: D6.2 (A), R10.2
unnamed: D7.2 (A), R11.2
unnamed: F1.1, P1.1
unnamed: F1.2, L1.1 (AA), R1.1
unnamed: L1.4 (SB), P1.2, R1.2
unnamed: R2.1, U1.1 (A/C)
unnamed: R3.1, U1.2 (C/A)
unnamed: T1.9 (SA), T1.13 (SD)
ZERO: P5.2, R6.2, R8.1, U1.3 (E)

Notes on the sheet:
12V ena veja buck 5V+3.3V druga veje (buck+LDO)

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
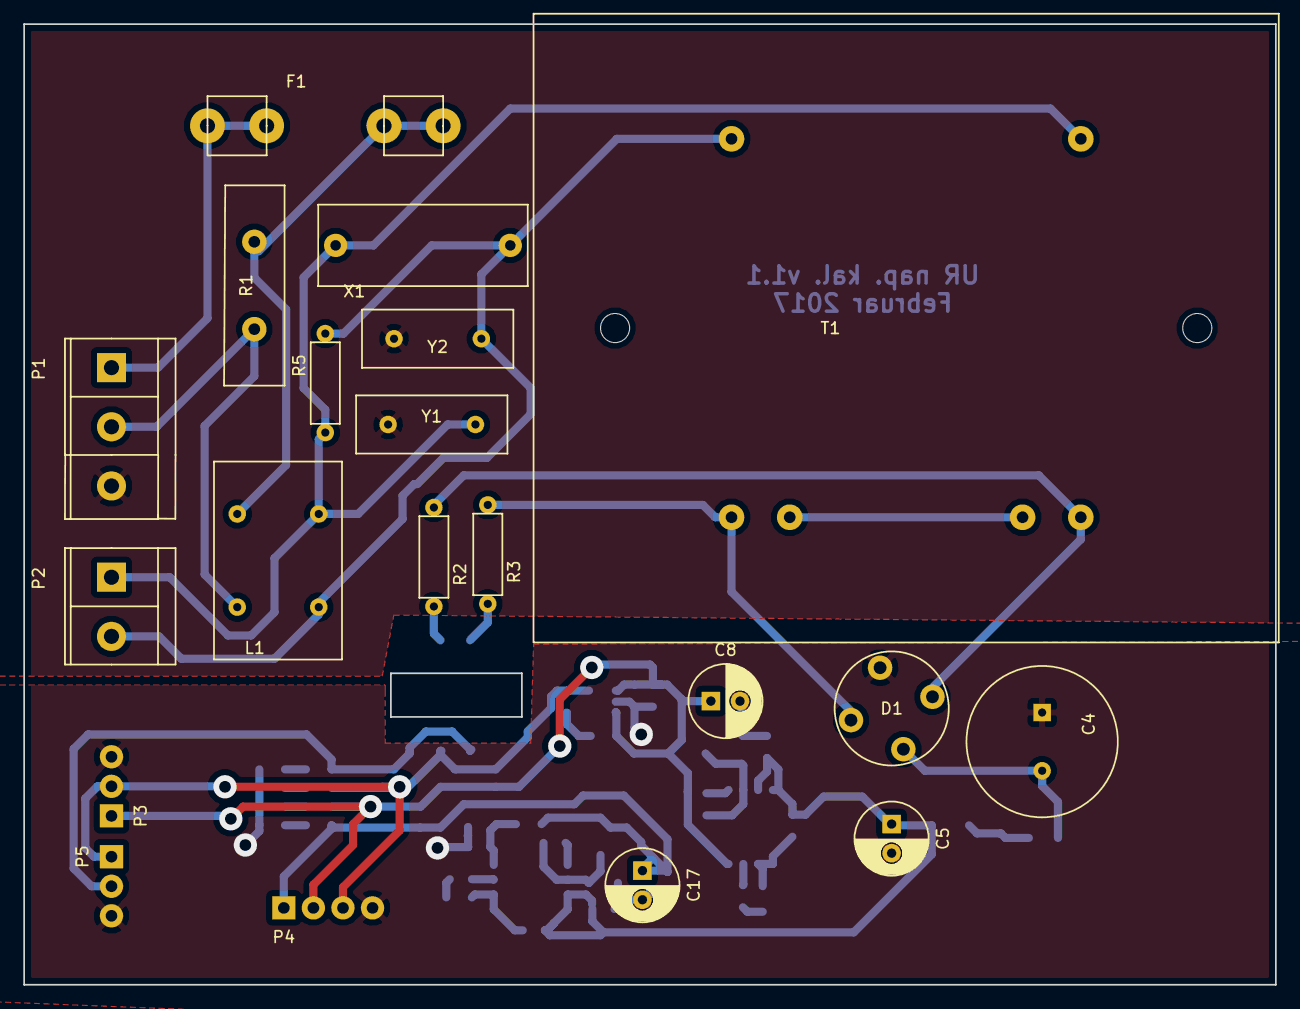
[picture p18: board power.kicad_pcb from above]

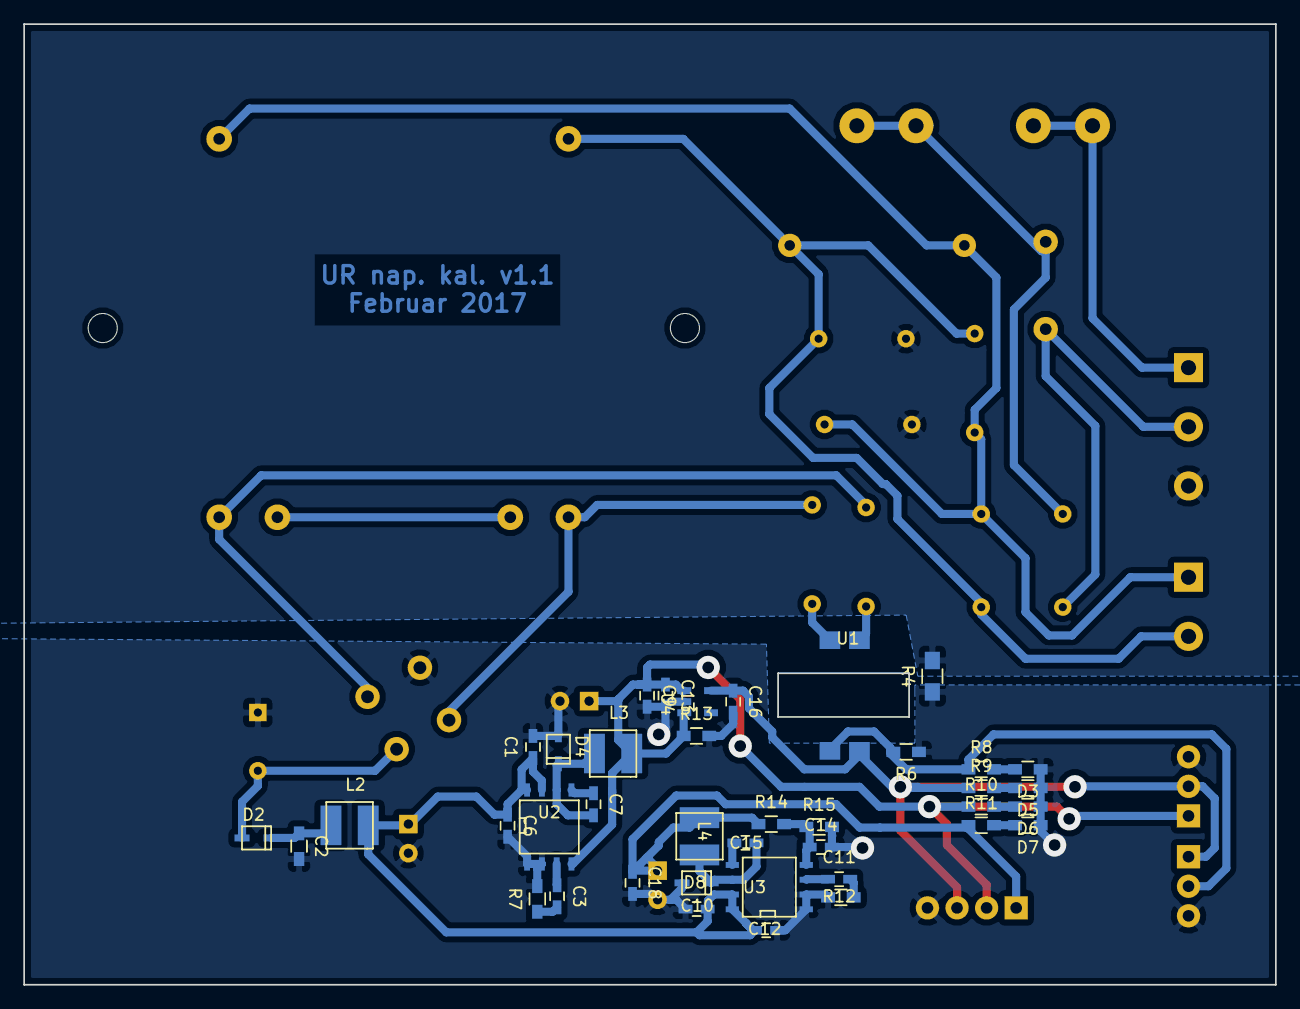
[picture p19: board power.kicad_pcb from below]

Board: 2 copper layers, 107.5 x 82.5 mm, 59 parts (39 on the bottom side), 32 nets.

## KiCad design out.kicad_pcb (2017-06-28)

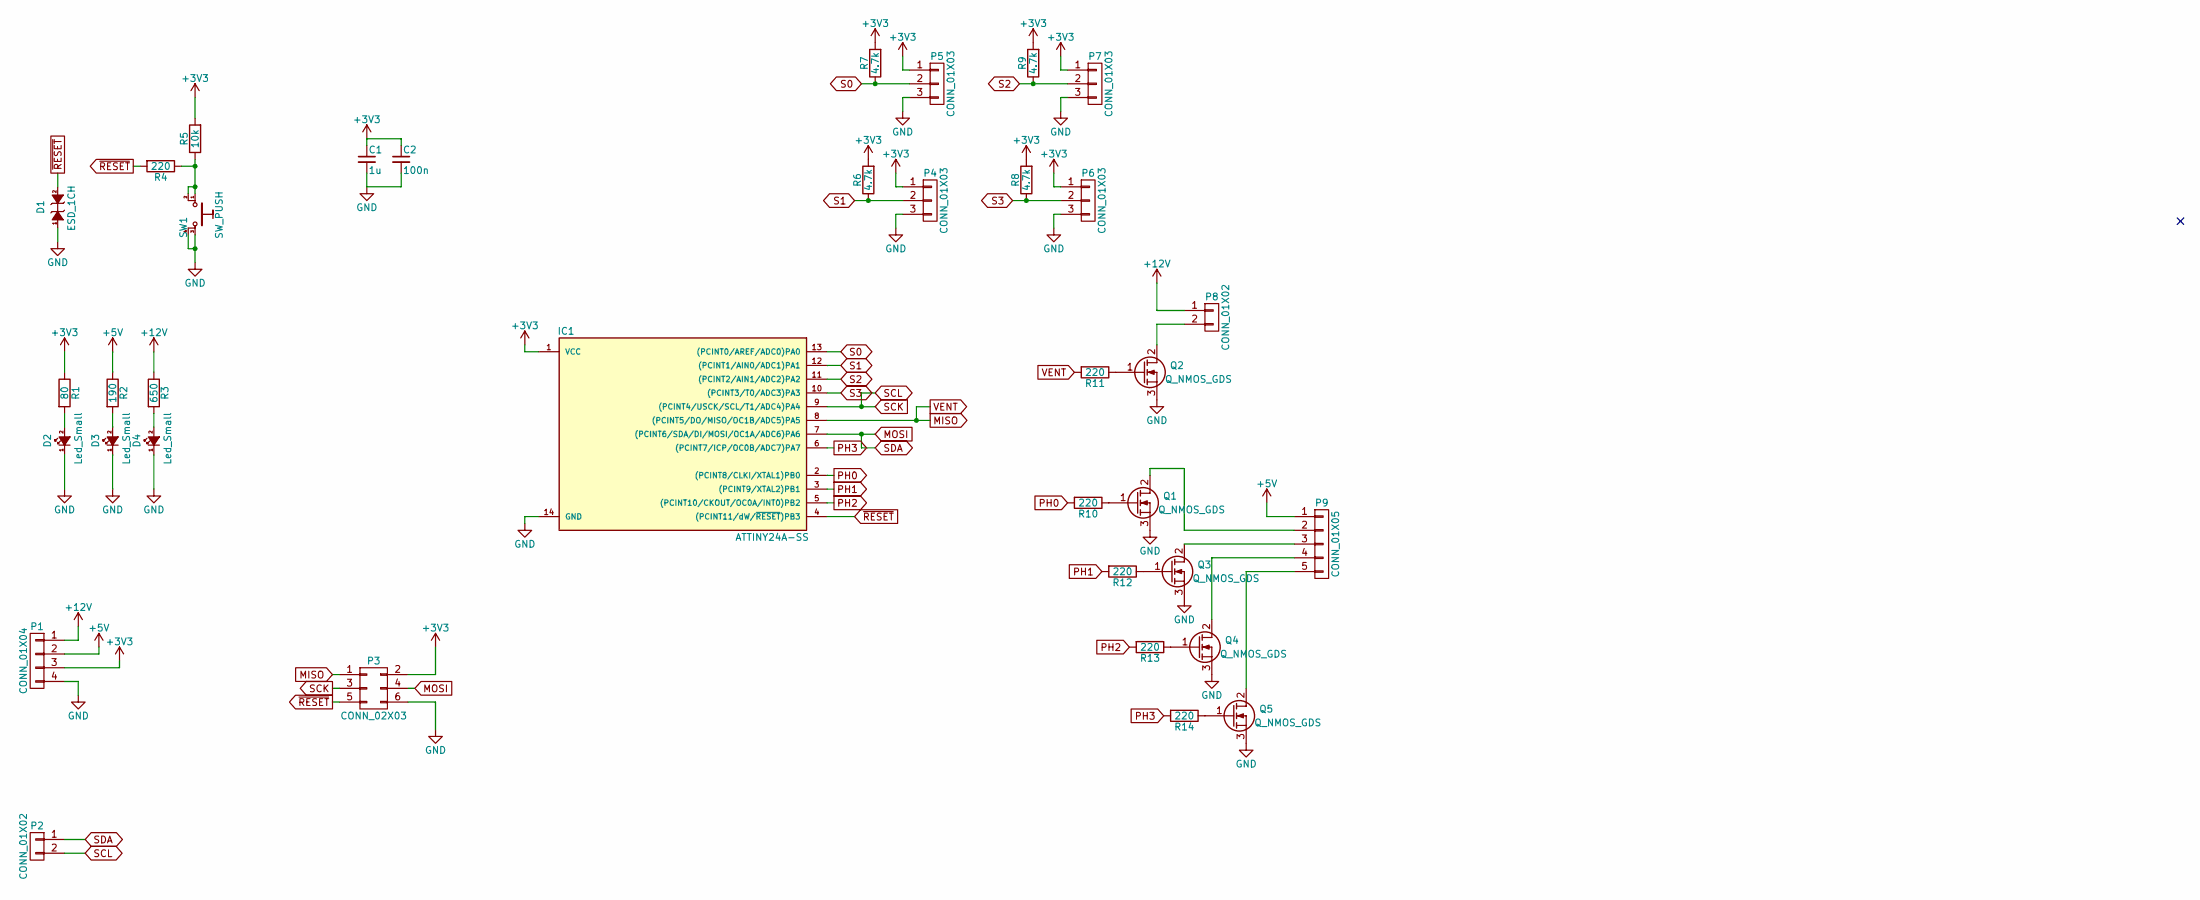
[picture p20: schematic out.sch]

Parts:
C1: 1u; C_0603_HandSoldering
C2: 100n; C_0603_HandSoldering
D1: ESD_1CH; SOD323F; Farnell number 8737517
D2, D3, D4: Led_Small; R_0603_HandSoldering
IC1: ATTINY24A-SS; SOIC-14_3.9x8.7mm_Pitch1.27mm
P1: CONN_01X04; CONN_4x1x2.54
P2: CONN_01X02; CONN_2x1x2.54
P3: CONN_02X03; IDC_Header_Straight_6pins
P4, P5, P6, P7: CONN_01X03; CONN_3x1x2.54
P8: CONN_01X02; CONN_2x1x5.08
P9: CONN_01X05; CONN_5x1x2.54
Q1, Q2, Q3, Q4, Q5: Q_NMOS_GDS; SOT89-3_Housing_Handsoldering_123; Farnell number 1834055
R1: 80; R_0603_HandSoldering
R2: 190; R_0603_HandSoldering
R3: 650; R_0603_HandSoldering
R4, R10, R11, R12, R13, R14: 220; R_0603_HandSoldering
R5: 10k; R_0603_HandSoldering
R6, R7, R8, R9: 4.7k; R_0603_HandSoldering
SW1: SW_PUSH; TACTILE_SWTICH_4PIN

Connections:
+3V3: C1.1, C2.1, IC1.1 (VCC), P1.3, P3.2, P4.1, P5.1, P6.1, P7.1, R1.1, R5.2, R6.2, R7.2, R8.2, R9.2
+5V: P1.2, P9.1, R2.1
+12V: P1.1, P8.1, R3.1
GND: C1.2, C2.2, D1.1 (K), D2.1 (K), D3.1 (K), D4.1 (K), IC1.14 (GND), P1.4, P3.6, P4.3, P5.3, P6.3, P7.3, Q1.3 (S), Q2.3 (S), Q3.3 (S), Q4.3 (S), Q5.3 (S), SW1.3, SW1.4
MISO: IC1.8 ((PCINT5/DO/MISO/OC1B/ADC5)PA5), P3.1, R11.2
MOSI: IC1.7 ((PCINT6/SDA/DI/MOSI/OC1A/ADC6)PA6), P2.1, P3.4
unnamed: D2.2 (A), R1.2
unnamed: D3.2 (A), R2.2
unnamed: D4.2 (A), R3.2
unnamed: P8.2, Q2.2 (D)
unnamed: P9.2, Q1.2 (D)
unnamed: P9.3, Q3.2 (D)
unnamed: P9.4, Q4.2 (D)
unnamed: P9.5, Q5.2 (D)
unnamed: Q1.1 (G), R10.1
unnamed: Q2.1 (G), R11.1
unnamed: Q3.1 (G), R12.1
unnamed: Q4.1 (G), R13.1
unnamed: Q5.1 (G), R14.1
unnamed: R4.1, R5.1, SW1.1, SW1.2
PH0: IC1.2 ((PCINT8/CLKI/XTAL1)PB0), R10.2
PH1: IC1.3 ((PCINT9/XTAL2)PB1), R12.2
PH2: IC1.5 ((PCINT10/CKOUT/OC0A/INT0)PB2), R13.2
PH3: IC1.6 ((PCINT7/ICP/OC0B/ADC7)PA7), R14.2
S0: IC1.13 ((PCINT0/AREF/ADC0)PA0), P5.2, R7.1
S1: IC1.12 ((PCINT1/AIN0/ADC1)PA1), P4.2, R6.1
S2: IC1.11 ((PCINT2/AIN1/ADC2)PA2), P7.2, R9.1
S3: IC1.10 ((PCINT3/T0/ADC3)PA3), P6.2, R8.1
SCK: IC1.9 ((PCINT4/USCK/SCL/T1/ADC4)PA4), P2.2, P3.3
~RESET: D1.2 (A), IC1.4 ((PCINT11/dW/~RESET~)PB3), P3.5, R4.2

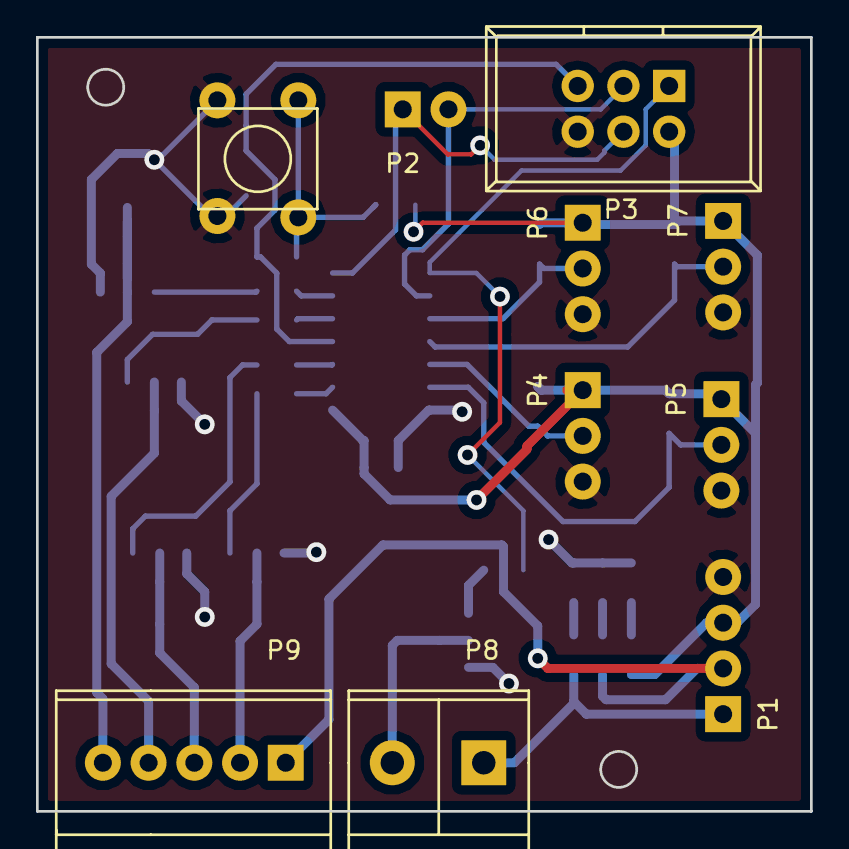
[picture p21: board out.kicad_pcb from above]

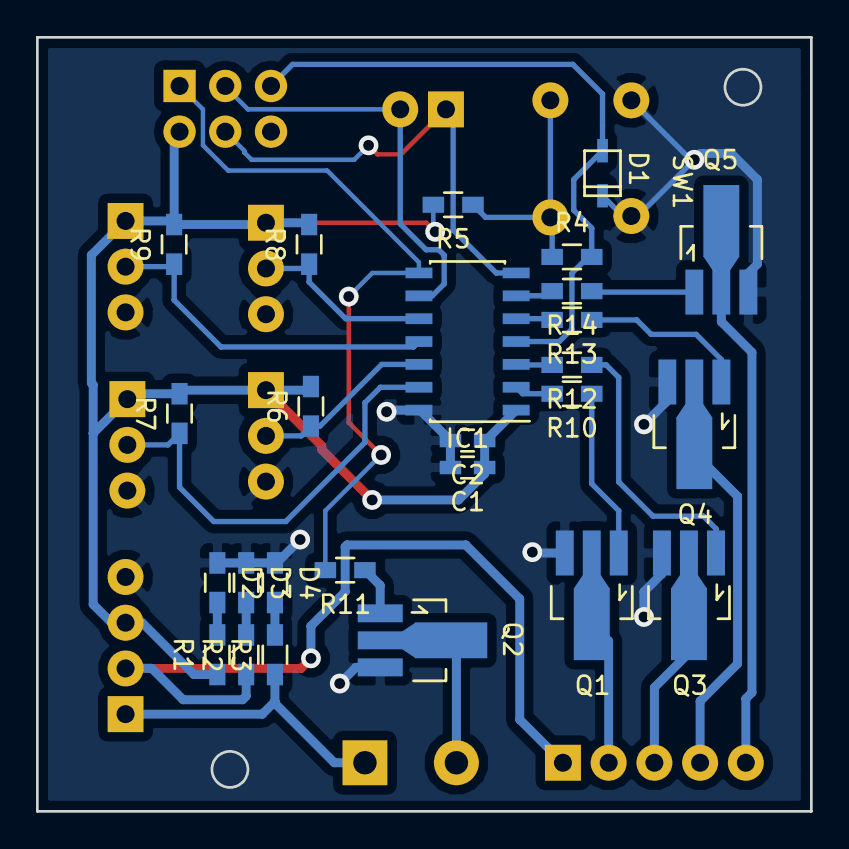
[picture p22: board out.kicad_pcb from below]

Board: 2 copper layers, 43.0 x 43.0 mm, 36 parts (27 on the bottom side), 30 nets.

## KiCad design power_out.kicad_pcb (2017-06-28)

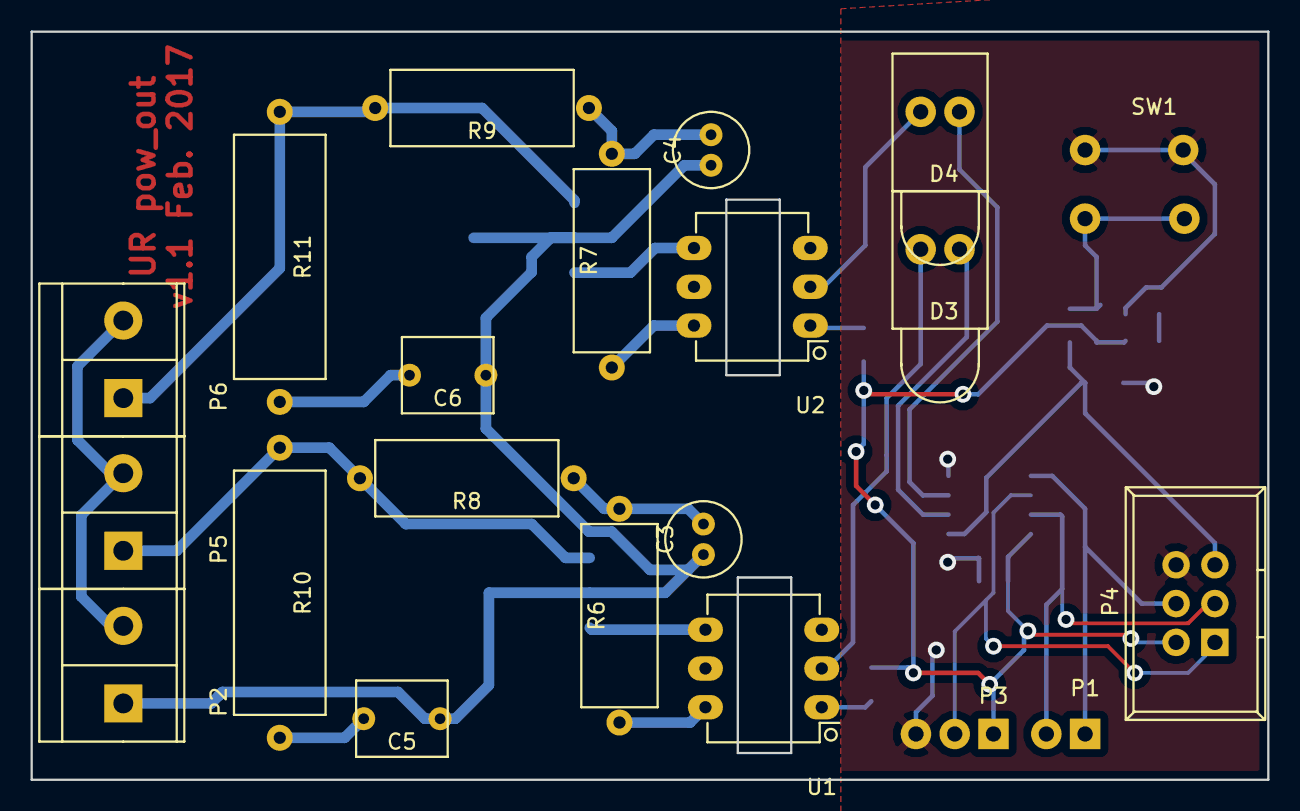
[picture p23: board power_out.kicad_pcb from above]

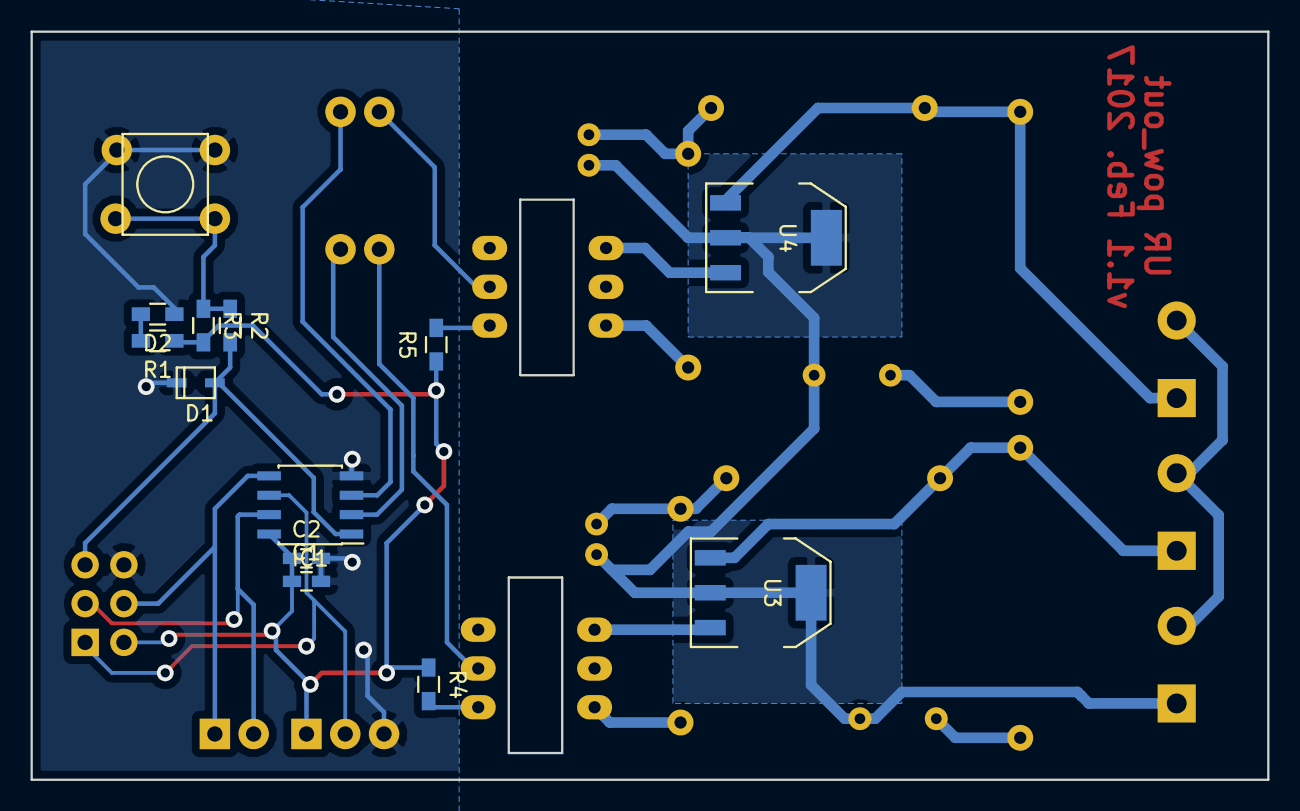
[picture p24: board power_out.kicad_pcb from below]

Board: 2 copper layers, 81.0 x 49.0 mm, 33 parts (12 on the bottom side), 26 nets.

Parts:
C1: 1u; C_0603_HandSoldering
C2: 100n; C_0603_HandSoldering
C3, C4: 200n; C_5x11_2
C5, C6: 50n 500V+; c_60pF
D1: ESD_1CH; SOD323F
D2: Led_Small; R_0603_HandSoldering
D3, D4: Led_Small; LED_0_1inch
IC1: ATTINY85-S; SOIC-8_3.9x4.9mm_Pitch1.27mm
P1: CONN_01X02; CONN_2x1x2.54
P2, P5, P6: CONN_01X02; CONN_2x1x5.08
P3: CONN_01X03; CONN_3x1x2.54
P4: CONN_02X03; IDC_Header_Straight_6pins
R1: R; R_0603_HandSoldering
R2, R4, R5: 220; R_0603_HandSoldering
R3: 10k; R_0603_HandSoldering
R6, R7: 180; CFR100
R8, R9: 2k4; CFR100
R10, R11: 39 2W; CFR200
SW1: SW_PUSH; TACTILE_SWTICH_4PIN
U1, U2: TRIAC_OPTOCOUPLER; DIP-6_W7.62mm_LongPads
U3, U4: TRIAC; SOT-223_THERMAL

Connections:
+3V3: C1.1, C2.1, IC1.8, P3.1, P4.2, R1.1, R3.2, R4.1, R5.1
/L: C3.2, C4.2, C5.2, C6.2, P2.1, U3.2, U4.2
/N: P2.2, P5.2, P6.2
GND: C1.2, C2.2, D1.1, D2.1, IC1.4, P3.3, P4.6, SW1.3, SW1.4
GRELEC: D3.1, IC1.2
LUC: D4.1, IC1.3
MISO: IC1.6, P3.2, P4.1
MOSI: IC1.5, P1.1, P4.4
unnamed: C3.1, R6.1, R8.2
unnamed: C4.1, R7.1, R9.2
unnamed: C5.1, R10.1
unnamed: C6.1, R11.1
unnamed: D2.2, R1.2
unnamed: D3.2, U1.2
unnamed: D4.2, U2.2
unnamed: P5.1, R8.1, R10.2, U3.1
unnamed: P6.1, R9.1, R11.2, U4.1
unnamed: R2.1, R3.1, SW1.1, SW1.2
unnamed: R4.2, U1.1
unnamed: R5.2, U2.1
unnamed: R6.2, U1.6
unnamed: R7.2, U2.6
unnamed: U1.4, U3.3
unnamed: U2.4, U4.3
SCK: IC1.7, P1.2, P4.3
~RESET: D1.2, IC1.1, P4.5, R2.2

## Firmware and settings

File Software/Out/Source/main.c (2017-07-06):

/*
 * main.c
 *
 *  Created on: 27. feb. 2017
 *      Author: urban
 */

#include <avr/io.h>
#include <util/delay.h>
#include <avr/interrupt.h>
#include <avr/pgmspace.h>
#include "hardware.h"
#include "blink.h"
#include "bittop.h"
#include "usi_i2c_slave.h"
#include "dht11.h"


// določimo I2C naslov (0x40)
extern char usi_i2c_slave_address;
extern char* USI_Slave_register_buffer[USI_SLAVE_REGISTER_COUNT];
char usi_i2c_slave_address=0x40;


/*
 * enum tip za koračne motorje
 */
typedef enum{
	ONE,
	TWO,
	THREE,
	FOUR
}stepper;

typedef enum{
	IDLE,
	LOAD,
	RUN
}stepper_run;

int main(void){
	sei();
	char load=0x00;
	char dir;
	char v;
	char error;
	char position_up=0x02;
	char position_down=0x00;
	char position_wnt_up;
	char position_wnt_down;
	uint16_t pos_wnt;
	uint16_t pos;
	char wtchdog;


	// default pozicija za koračni motor
	stepper my_stepper=ONE;

	stepper_run states=IDLE;

	// konfiguracija vhodnih in izhodnih pinov
	IOCfg();

	//uint8_t data[4];

	//initDHT();

	// inicializacija na I2C
	USI_I2C_Init(0x40);


	//sensors[0].data[0]=0x15;
	//sensors[0].data[2]=0x18;


	// I2C register povežemo z naslovi spremenljivk

	// 12V izhod
	USI_Slave_register_buffer[0]=&leds[0].value;
	// senzor 0 -> vlaga
	USI_Slave_register_buffer[1]=&sensors[0].data[0];
	// senzor 0 -> temperatura
	USI_Slave_register_buffer[2]=&sensors[0].data[2];
	// senzor 1 -> vlaga
	USI_Slave_register_buffer[3]=&sensors[1].data[0];
	// senzor 1 -> temperatura
	USI_Slave_register_buffer[4]=&sensors[1].data[2];
	// senzor 2 -> vlaga
	USI_Slave_register_buffer[5]=&sensors[2].data[0];
	// senzor 2 -> temperatura
	USI_Slave_register_buffer[6]=&sensors[2].data[2];
	// register za napake
	USI_Slave_register_buffer[7]=&error;
	// watchdog (ni še uporabljen)
	USI_Slave_register_buffer[8]=&wtchdog;
	// pozicija motorja
	USI_Slave_register_buffer[9]=&load;
	USI_Slave_register_buffer[10]=&position_wnt_up;
	USI_Slave_register_buffer[11]=&position_wnt_down;
	USI_Slave_register_buffer[12]=&position_up;
	USI_Slave_register_buffer[13]=&position_down;

	_delay_ms(1000);

	for(;;){

		switch(states){
			case IDLE:
				if (load==1){
					load=0;
					states=LOAD;
				}
				break;
			case LOAD:
				pos_wnt=(position_wnt_up<<8)|position_wnt_down;
				pos=(position_up << 8)|position_down;
				if(pos_wnt-pos >= 0)dir=1;
				else dir=0;

				states=RUN;
				break;
			case RUN:
				if((pos_wnt-pos)!=0){
					switch(my_stepper){
						case ONE:
							leds[1].value=1;
							if (dir==1) my_stepper=TWO;
							else my_stepper=FOUR;
							break;
						case TWO:
							leds[2].value=1;
							if (dir==1) my_stepper=THREE;
							else my_stepper=ONE;
							break;
						case THREE:
							leds[3].value=1;
							if (dir==1) my_stepper=FOUR;
							else my_stepper=TWO;
							break;
						case FOUR:
							leds[4].value=1;
							if (dir==1) my_stepper=ONE;
							else my_stepper=THREE;
							break;
					}
					for (uint8_t i=1; i<LED_NUM;i++){
						SetValue(&leds[i]);
					}

					if(dir==1)pos++;
					else pos--;

					position_up=(pos>>8)&0x00FF;
					position_down=pos&0x00FF;
				}
				else{
					states=IDLE;
				}
				break;
		}


		// zajem podatkov za posamezni senzor
		// vrne 0, če je zajem z napako oziroma ni uspel
		// in ponastavi vse registre na 0
		v=fetchData(&sensors[0]);
		if (v==0){
			for (uint8_t i=0; i<5;i++){
				sensors[0].data[i]=0;
			}
		}

		v=fetchData(&sensors[1]);
		if (v==0){
			for (uint8_t i=0; i<5;i++){
				sensors[1].data[i]=0;
			}
		}


		v=fetchData(&sensors[2]);
		if (v==0){
			for (uint8_t i=0; i<5;i++){
				sensors[2].data[i]=0;
			}
		}

		// nastavi 12V izhod na vrednost
		SetValue(&leds[0]);


	}
	return 0;
}

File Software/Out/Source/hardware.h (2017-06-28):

/*
 * hardware.h
 *
 *  Created on: 16. jan. 2017
 *      Author: Urban Rupnik
 *      City: Zadlog 42
 */

#include <avr/io.h>
#include <util/delay.h>


#ifndef HARDWARE_H_
#define HARDWARE_H_

	#define DDR_USI			DDRA
	#define PORT_USI		PORTA
	#define PIN_USI			PINA
	#define PORT_USI_SDA	PA6
	#define PORT_USI_SCL	PA4
	#define PIN_USI_SDA		PINA6
	#define PIN_USI_SCL		PINA4


	#define VENT 			PB3
	#define VENT_PORT		PORTB
	#define VENT_DIR_PORT	DDRB

	#define PH0 			PB0
	#define PH0_PORT		PORTB
	#define PH0_DIR_PORT	DDRB

	#define PH1 			PB1
	#define PH1_PORT		PORTB
	#define PH1_DIR_PORT	DDRB

	#define PH2 			PB2
	#define PH2_PORT		PORTB
	#define PH2_DIR_PORT	DDRB

	#define PH3 			PA7
	#define PH3_PORT		PORTA
	#define PH3_DIR_PORT	DDRA

	#define S0				PA0
	#define S0_PORT 		PORTA
	#define S0_DIR_PORT		DDRA
	#define S0_VALUE_REG	PINA

	#define S1				PA1
	#define S1_PORT 		PORTA
	#define S1_DIR_PORT		DDRA
	#define S1_VALUE_REG	PINA

	#define S2				PA2
	#define S2_PORT 		PORTA
	#define S2_DIR_PORT		DDRA
	#define S2_VALUE_REG	PINA

	#define S3				PA3
	#define S3_PORT 		PORTA
	#define S3_DIR_PORT		DDRA
	#define S3_VALUE_REG	PINA


#endif /* HARDWARE_H_ */

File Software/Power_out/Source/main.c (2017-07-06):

/*
 * main.c
 *
 *  Created on: 27. feb. 2017
 *      Author: urban
 */

#include <avr/io.h>
#include <util/delay.h>
#include <avr/interrupt.h>
#include "hardware.h"
#include "blink.h"
#include "bittop.h"
#include "usi_i2c_slave.h"

// določimo I2C naslov (0x41)

extern char usi_i2c_slave_address;
extern char* USI_Slave_register_buffer[USI_SLAVE_REGISTER_COUNT];
char usi_i2c_slave_address=0x41;

uint8_t cnt;
Input zero;

int main(void){

	sei();
	char a;
	char b;
	char error;
	char wtchdog;

	// inicializacija vhodnih in izhodnih pinov ter struktur
	IOCfg();

	// interrupt od zero
	SETBIT(GIMSK, PCIE);
	SETBIT(PCMSK, zero.pcint);


	//Timer1 prescaler (8/8)
	SETBITS(TCCR1, BIT(CS12));
	CLEARBITS(TCCR1, BIT(CS12)|BIT(CS10)|BIT(CS11));

	//interupt od timerja
	OCR1A=0x99;
	SETBIT(TIMSK, OCIE1A);


	// I2C inicializacija z naslovom 0x41
	USI_I2C_Init(0x41);


	// interni registri I2C komunikacije

	// izhod za grelec
	USI_Slave_register_buffer[0]=&leds[0].value;
	// duty za grelec
	USI_Slave_register_buffer[1]=&leds[0].duty;
	// izhod za luc
	USI_Slave_register_buffer[2]=&leds[1].value;
	// duty za luc
	USI_Slave_register_buffer[3]=&leds[1].duty;
	// register za napake
	USI_Slave_register_buffer[4]=&error;
	// watchdog (ni še)
	USI_Slave_register_buffer[5]=&wtchdog;

	_delay_ms(1000);

	for(;;){
		//_delay_ms(100);
		//leds[0].duty=50;
		//leds[1].duty=50;
		for (uint8_t i=0; i<LED_NUM;i++){
			SetValue(&leds[i]);
		}
		_delay_ms(1000);
	}
	return 0;
}


ISR(PCINT0_vect){
	if(BITVAL(*zero.value_reg,zero.pin)){
		cnt=0;
		for (uint8_t i=0; i<LED_NUM;i++){
//			if(!leds[i].duty){
//				leds[i].value=1;
//			}
//			else
				leds[i].value=1;

			SetValue(&leds[i]);
		}
	}
}

ISR(TIM1_COMPA_vect){
	cnt++;
	for (uint8_t i=0; i<LED_NUM;i++){
		if((100-leds[i].duty)<cnt){
			leds[i].value=0;
			SetValue(&leds[i]);
		}
	}
}

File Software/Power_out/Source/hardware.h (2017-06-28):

/*
 * hardware.h
 *
 *  Created on: 16. jan. 2017
 *      Author: Urban Rupnik
 *      City: Zadlog 42
 */

#include <avr/io.h>
#include <util/delay.h>


#ifndef HARDWARE_H_
#define HARDWARE_H_

	#define DDR_USI			DDRB
	#define PORT_USI		PORTB
	#define PIN_USI			PINB
	#define PORT_USI_SDA	PB0
	#define PORT_USI_SCL	PB2
	#define PIN_USI_SDA		PINB0
	#define PIN_USI_SCL		PINB2


	#define GRELEC 			PB3
	#define GRELEC_PORT		PORTB
	#define GRELEC_DIR_PORT	DDRB

	#define LUC 			PB4
	#define LUC_PORT		PORTB
	#define LUC_DIR_PORT	DDRB

	#define ZERO			PB1
	#define ZERO_PORT		PORTB
	#define ZERO_DIR_PORT	DDRB
	#define ZERO_VALUE_REG 	PINB
	#define ZERO_PCINT		PCINT1



#endif /* HARDWARE_H_ */
